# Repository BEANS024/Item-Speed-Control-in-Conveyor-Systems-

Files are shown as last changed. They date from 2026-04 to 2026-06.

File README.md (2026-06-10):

# **ITEM SPEED CONTROL IN CONVEYOR SYSTEMS FOR CONSISTENT ITEM DISCHARGE UTILIZING IR PROXIMITY SENSORS**

*A requirement to pass the course CONTROLS ENGINEERING & SENSORS ENGINEERING (collaborative requirement) - [A Semestral Project]*


<!-- isometric view of project -->





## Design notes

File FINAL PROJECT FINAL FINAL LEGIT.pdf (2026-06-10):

Republic of the Philippines

### BATANGAS STATE UNIVERSITY

The National Engineering University Alangilan Campus
Golden Country Homes, Alangilan Batangas City, Batangas, Philippines 4200
Tel Nos.: (+63 43) 425-0139 local 2121 / 2221
E-mail Address: coe.alangilan@g.batstate-u.edu.ph | Website Address: http://www.batstate-u.edu.ph (http://www.batstateu-u.edu.ph)
College of Engineering - Department of Electronics Engineering Bachelor of Science in Mechatronics Engineering

“Item Speed Control in Conveyor Systems for consistent inventory discharge utilizing IR Proximity Sensors”

ICE - 405 SENSORS ENGINEERING & ECE - 425 CONTROL SYSTEMS ENGINEERING

MExE-3202

Prepared by:

23-04314
23-00685
23-05791
23-04074

Instructor
Engr. JOHN KRISTOFFER L. JAVAREZ Engr. JONATHAN I. TEJADA

May 26, 2026
Leading Innovations, Transforming Lives, Building the Nation page 1

Alangilan Campus
Golden Country Homes, Alangilan Batangas City, Batangas, Philippines 4200
Tel Nos.: (+63 43) 425-0139 local 2121 / 2221
E-mail Address: coe.alangilan@g.batstate-u.edu.ph | Website Address: http://www.batstate-u.edu.ph (http://www.batstateu-u.edu.ph)
College of Engineering - Department of Electronics Engineering Bachelor of Science in Mechatronics Engineering

### I. Abstract

This project presents the design, mathematical modeling, simulation, and prototype implementation of a closed-loop conveyor object spacing control system utilizing infrared proximity sensors for consistent inventory discharge. The system employs an asymmetric Proportional-Integral (PI) control strategy implemented on an Arduino Uno microcontroller, using two HW201 infrared proximity sensors, an L298N motor driver module, and a custom 3D-printed conveyor belt driven by a TT DC gear motor. The control objective is to maintain a consistent inter-item discharge interval of 900 milliseconds by dynamically adjusting conveyor belt speed in response to real-time spacing feedback detected at the entry and discharge points of the conveyor.

The mathematical foundation was developed through transfer function and state-space modeling of the electrical, mechanical, electromechanical, and gear subsystems. An asymmetric PI control law with separate braking and accelerating gain sets was implemented alongside anti-windup protection, asymmetric PWM ramping, and a feed-forward pre-compensation mechanism to mitigate the belt's inherent transport delay. A First-In First-Out queue structure preserves measurement-to-item correspondence during multi-object operation.

MATLAB and Simulink were used for system analysis and simulation, supported by an interactive digital twin for controller validation prior to hardware deployment. Prototype testing under close-spacing, far-spacing, and mixed-spacing conditions confirmed the system's ability to apply accurate bidirectional corrective actions. Results demonstrate the effectiveness of closed-loop PI control in improving conveyor discharge consistency, accuracy, and adaptability for industrial automation applications.

Leading Innovations, Transforming Lives, Building the Nation page 2

Alangilan Campus
Golden Country Homes, Alangilan Batangas City, Batangas, Philippines 4200
Tel Nos.: (+63 43) 425-0139 local 2121 / 2221
E-mail Address: coe.alangilan@g.batstate-u.edu.ph | Website Address: http://www.batstate-u.edu.ph (http://www.batstateu-u.edu.ph)
College of Engineering - Department of Electronics Engineering Bachelor of Science in Mechatronics Engineering

### II. Introduction

This project titled “Item Speed Control in Conveyor Systems for consistent inventory discharge utilizing IR Proximity Sensors” seeks to portray in small scale how closed-loop PI controllers can be utilized in conveyor systems. The project uses a custom designed 3D printed conveyor system which utilizes a DC gear motor to drive and actuate the conveyor belt. The entire logic of the system is programmed and controlled through an arduino uno along with two infrared proximity sensors that are used to detect the presence and determine the spacing of objects along the conveyor belt. By utilizing the detection signals produced by the infrared sensors, object spacing can be monitored and belt discharge can be controlled. If the said objects are too close to one another the system would slow down to prevent item congestion in a supposed station after the belt, and if objects were to have a further distance from one another than the target set point the system would speed up for the second object to compensate for delivery delay.

Engineering an automated system that integrates mechanics, electronics, and computing into a singular system is the interdisciplinary engineering field of mechatronics, however being able to control every component to work in unison to function as a singular system is only the next step into mechatronics engineering. Closed-loop control is an essential concept in mechatronics for automated systems because it allows continuous operations based on real-time feedback within the system. Unlike open-loop systems, which operate without considering the actual output condition, closed-loop systems utilize sensors to detect system behavior and provide feedback to the controller for corrective action. This enables the system to maintain accuracy, stability, and consistent performance even when disturbances or varying operating conditions are present. It is widely used in industrial automation, robotics, conveyor systems, motor speed regulation, and manufacturing processes where maintaining controlled and stable Leading Innovations, Transforming Lives, Building the Nation page 3

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

operation is critical. Through continuous feedback and adjustment, closed-loop control helps minimize errors, reduce manual intervention, improve safety, and optimize overall system performance. In the proposed conveyor speed control system, applying a closed-loop control plays an essential role in this system for monitoring and regulating inventory speed along the conveyor belt for maintaining a consistent inventory discharge rate. By applying closed-loop control in this project, the project design achieves being an automated mechatronic system which improves efficiency, precision, and reliability by allowing machines to adapt automatically to change within the system. Unlike traditional conveyor systems with no such application of logic controllers, this system obtains its feedback for its closed loop system from the infra-red proximity sensors allowing the controller to dynamically adjust the conveyor speed in response to changing conditions. This adaptive behavior demonstrates the practical importance of closed-loop control in achieving efficient and reliable automated material handling operations

OBJECTIVES:

1. To design a proportional control system for conveyor belts that maintains optimal

material flow by adjusting speed based on inventory item flow, and its

corresponding mathematical control model.

2. To develop a belt control system that implements the functionality of an IR sensor

module to regulate item flow for consistent discharge.

3. To analyze and evaluate the system’s performance in terms of the following
- Speed response
- Control accuracy
- Sensor reliability

Leading Innovations, Transforming Lives, Building the Nation page 4

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

### III. System Description

HARDWARE CONFIGURATION
The system is tailored to showcase the application of a closed-loop feedback architecture in automated conveyor systems. The overall mechanical hardware design is structured so the project is suited for safe DC power. The primary power supply supplies approximately 13.7V that is then regulated through a LM2596 DC-DC step-down buck converter. To improve the electrical safety of the electrical components in this project, a toggle switch is used as the main power switch, so current doesn't flow immediately after plugging in the power supply. Two limit switch push buttons are then utilized to create a start and stop function in the project, this allows for confirmation that all components are functional before manually starting the system and when observation is done the system can them be manually and safely switched off without aggressively unplugging the power, this also allows the operator to manually switch off the project if any errors were to occur and then resetting via the start button. Further hardware configuration can be observed in figure 2.1.

Leading Innovations, Transforming Lives, Building the Nation page 5

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

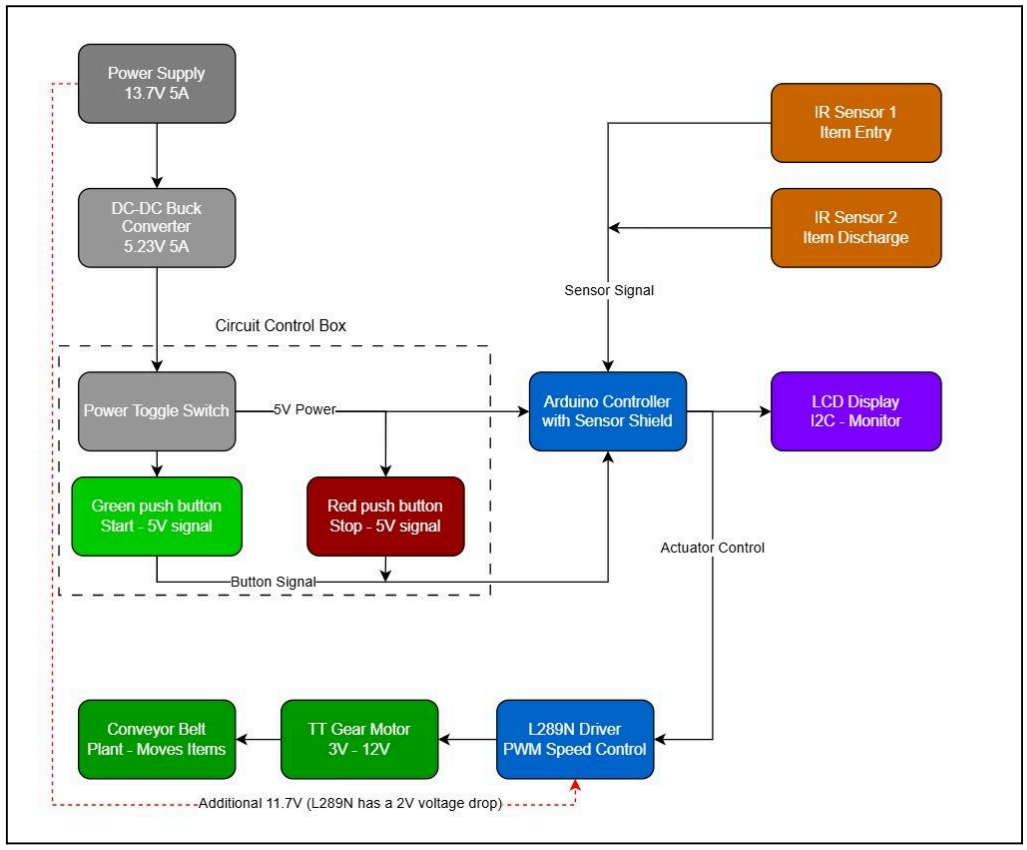
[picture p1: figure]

“figure 2.1. (Hardware Configuration)” SENSOR

The sensor to be used in this system is a HW201 Infrared (IR) Sensor. This sensor measures and detects the infrared radiation which is emitted from the TR transmitter and when it hits an object the radiation would then be reflected into the IR receiver. This process is then utilized to create a signal output. When no radiation is reflected, the electrical resistance is increased, then if radiation is reflected, the resistance will decrease (resistance will vary on the distance it was reflected from).

Leading Innovations, Transforming Lives, Building the Nation page 6

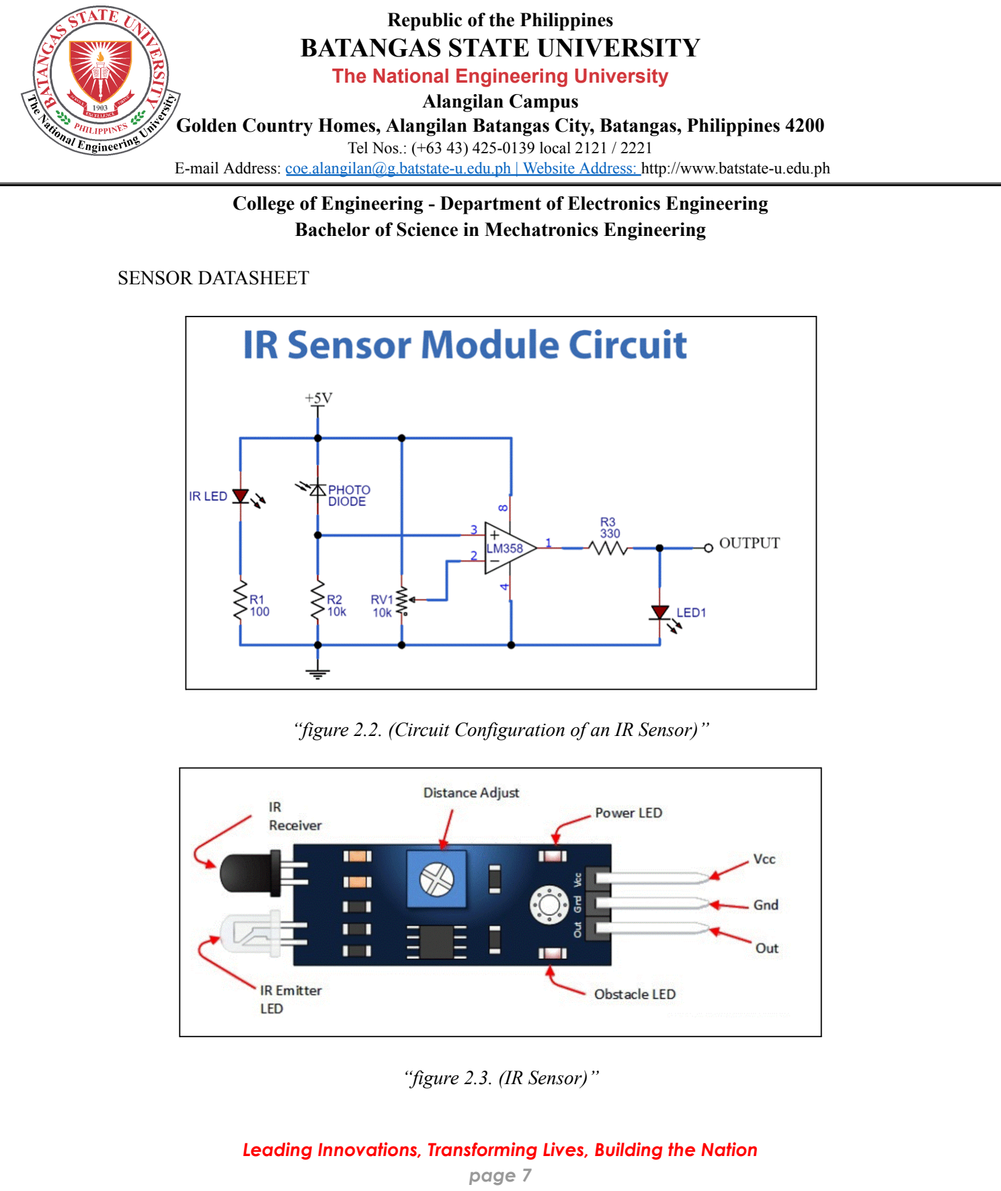
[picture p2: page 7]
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

SENSOR DATASHEET

“figure 2.2. (Circuit Configuration of an IR Sensor)”

“figure 2.3. (IR Sensor)”

Leading Innovations, Transforming Lives, Building the Nation page 7

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

Pinouts of HW201 Module

PIN NAME | DESCRIPTION
VCC | Power Supply Input
GND | Power Supply Ground
OUT/SIGNAL | Active High Output

SPECIFICATIONS

- Main Chip: LM393
- Detection Distance: 2~30cm
- Detection Angle: 35 °
- Working Voltage: 3.3V~5V
- Board Size: 31 * 14mm / 1.22 * 0.55in
- Board Weight(1pc): 3g
- 20mA supply current
- 2 to 30cm adjustable sensing range (on-board Potentiometer)

SENSOR CONDITIONING

The HW201 infrared (IR) sensor module utilizes an LM358 operational amplifier to perform signal conditioning on the output of the IR receiver. When infrared light emitted by the transmitter is reflected by a nearby object and detected by the photodiode (or phototransistor), it generates a small analog voltage proportional to the reflected intensity. However, this signal is typically weak and susceptible to noise, making it unsuitable for direct use in control systems.

Leading Innovations, Transforming Lives, Building the Nation page 8

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

To address this, the LM358 op-amp is configured as a comparator with adjustable threshold. One input of the LM358 receives the analog signal from the IR receiver, while the other input is connected to a reference voltage set by an onboard potentiometer. The amplifier compares these two voltages and produces a clean digital output: when the sensor signal exceeds the threshold, the output switches state (HIGH or LOW), indicating object detection.

This signal conditioning process improves reliability by amplifying the weak sensor signal, filtering out minor fluctuations, and converting it into a stable, noise-resistant digital signal that can be easily interfaced with microcontrollers such as an Arduino or PLC systems.

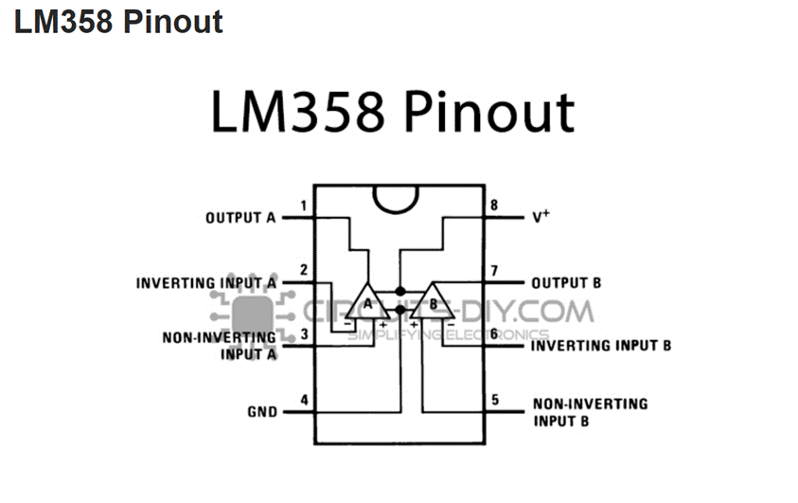
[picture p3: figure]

“figure 2.4. (IR Sensor Op-Amp)”

Leading Innovations, Transforming Lives, Building the Nation page 9

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

IMPLEMENTATION OF THE SENSOR IN THE SYSTEM

To manage the flow of inventory items within the system, an IR proximity sensor is implemented to detect discrete events corresponding to item entry onto the conveyor belt. Each detection provides a measurable signal indicating the presence of an item, enabling the system to track the timing and frequency of incoming materials. This event-based sensing approach allows the system to estimate the infeed rate and monitor consistency in item flow. The acquired data is then used as feedback for adjusting conveyor speed to maintain a stable discharge rate. By integrating discrete sensing with control logic via an Arduino Uno, the system achieves more reliable and responsive inventory handling.

ELECTRICAL DESIGN
An arduino uno R3 is used as this project's main embedded microcontroller to handle the project’s logic and control calculations. The I2C ports are used so the operator can monitor the real time speed, gap, item count, and error in the system. The DC-DC buck converter ensures that approximately 5.23V is used to power the electrical components and the 13.7V from the power supply is used as additional power for the TT gear motor wish has an operating voltage of 3-12V, in this set up 13.7V is used because as the additional voltage flows through the motor driver module L298N there is a 2V voltage drop. Then two infra-red proximity sensors are connected to the arduino board, because the system only requires the sensors to be used to detect objects entering and leaving the belt, the sensors deliver discrete signals to the digital GPIO’s.

Leading Innovations, Transforming Lives, Building the Nation page 10

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

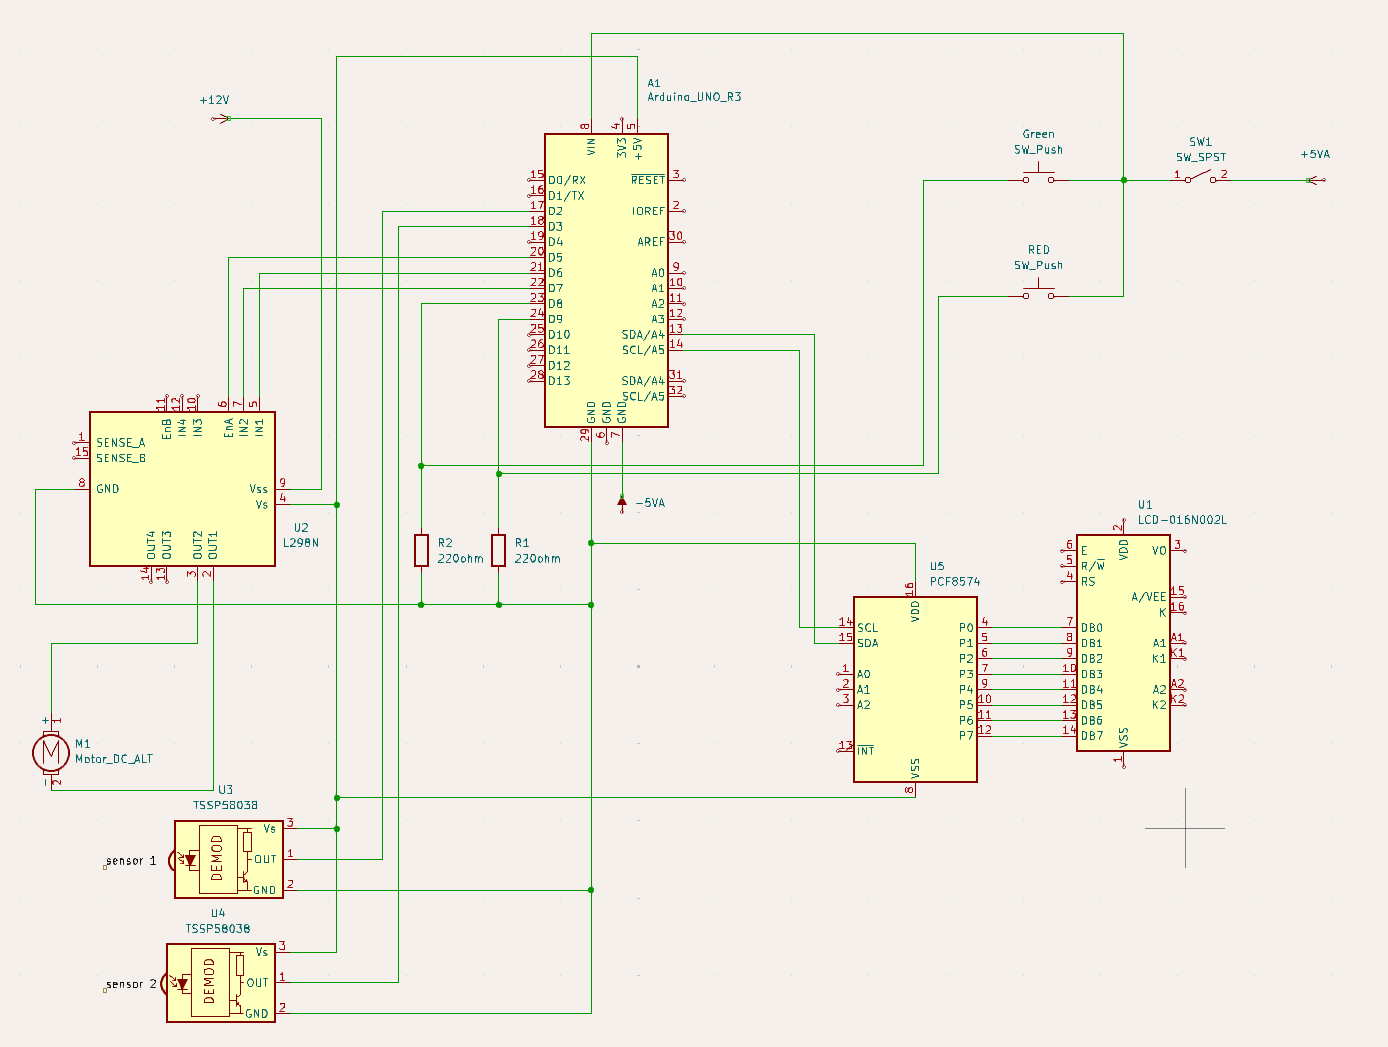
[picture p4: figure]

“figure 2.5. (Electrical Schematic)”

CAD DESIGN AND MANUFACTURING
The project was then designed on Solidworks to have a conceptual design before physically assembling it. The system features a custom made conveyor belt which utilizes a custom made timing belt design. The belt length is 368mm from the gear to gear centers. The custom parts were then 3D printed with PETG, the total mass used for the prints is 527.73g. The parts manufactured for this project consists of an inflow ramp which has a 30 degree angle of tilt and a mounting slot for the infra-red proximity sensor. A vertical elevation support for the LCD display which allows the operator to view the real-time system conditions at a comfortable viewing angle. For the system discharge a basket is placed to receive items that will be discharged from the conveyor system. screw supports were made for the conveyor belt to hold it Leading Innovations, Transforming Lives, Building the Nation page 11

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

in place while retaining the modular ability of the conveyor if modifications are needed. As for the conveyor itself, a motor chassis was made to hold the DC motor in place and to protect it from external disturbances. Two gears are present in the conveyor system, one being the driver pulley and the other being the driven pulley. The frame of the conveyor system is designed to hold the belt in a fixed position to prevent belt slack without the need of additional tension. Finally for the belt, it uses a timing belt structure to allow it to be driven by the pulleys by having both rigid bodies interlock with each other. To achieve the timing belt design 98 individual pieces were printed using a print in place technique with a 0.5mm tolerance to allow for optimal flexibility of the belt for the conveyor system.

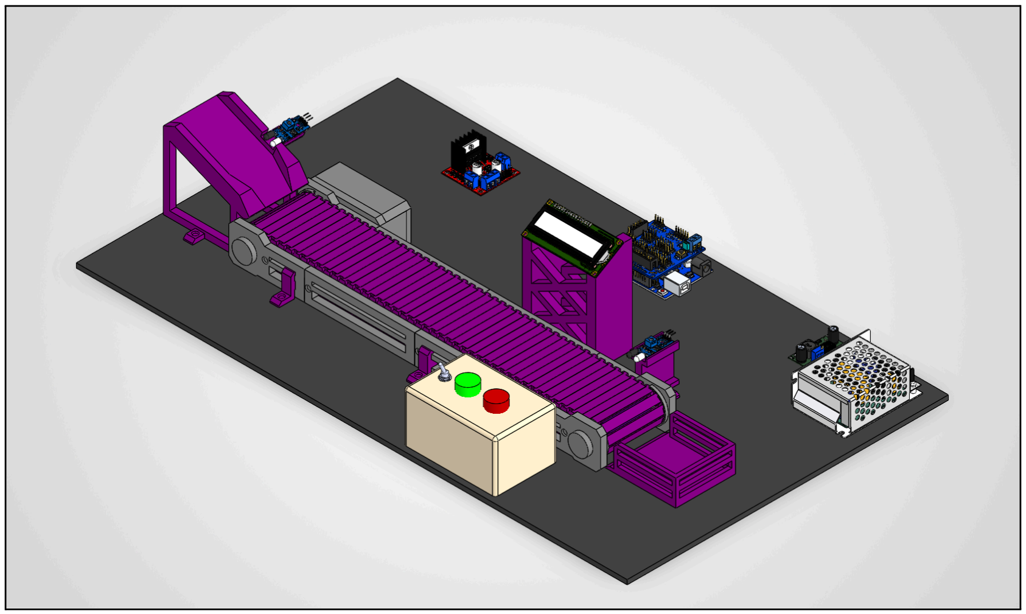
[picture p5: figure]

“figure 2.6. (CAD Isometric view)”

Leading Innovations, Transforming Lives, Building the Nation page 12

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

“figure 2.7. (CAD Top view)

“figure 2.8. (CAD Front view)”

Leading Innovations, Transforming Lives, Building the Nation page 13

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

CONTROL SYSTEM

For this automated conveyor system where speed control is the main variable to be controlled, figure 2.9. provides a basic input output diagram of how the system works overall. where items entering the conveyor serves as the input then the conveyor system regulates the speed ensuring that the items on the belt are discharged consistently. The items that are discharged from the conveyor belt would also be the output of the system.

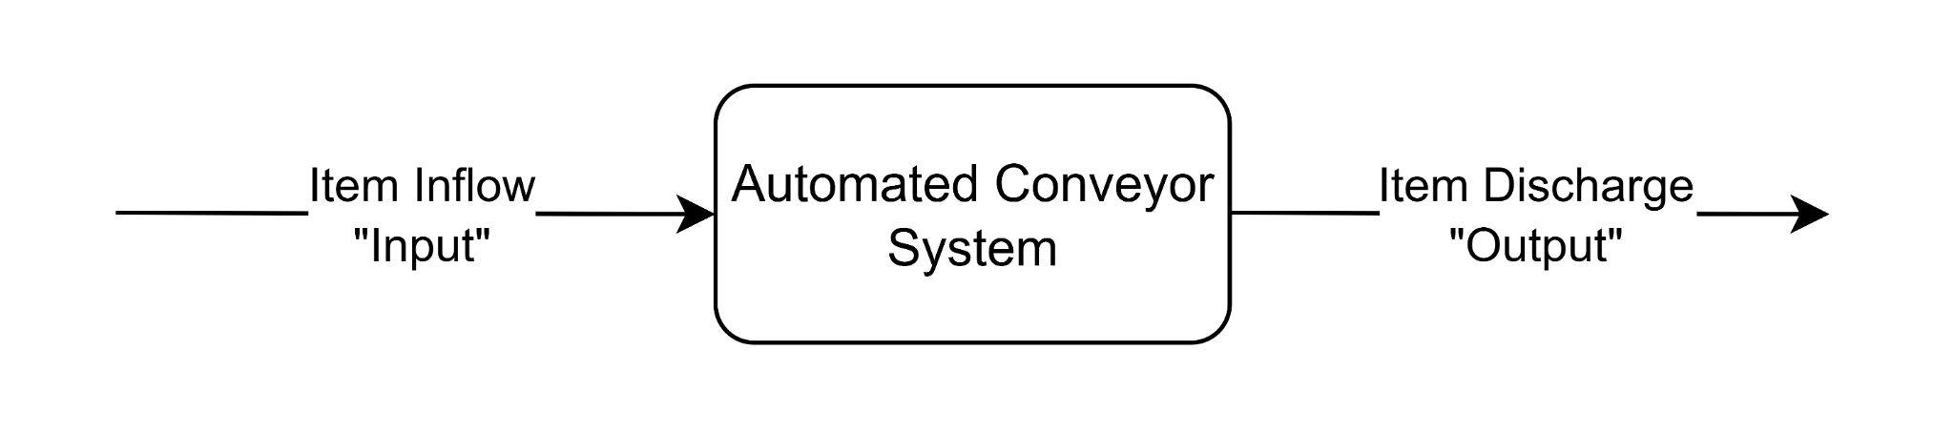
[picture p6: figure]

“figure 2.9. (Basic input output diagram)”

In this automated conveyor system, maintaining a consistent discharge rate is essential for material handling in automated systems especially in industrial applications. For the control law to be applied to this project its important to choose the most appropriate PID controller was considered, however it was deemed overly complex for this system since the main priority is creating a stable system response and reducing steady state errors, there is no need for the system to predict errors also this effects the arduino computational load hindering the response time of the system.

Leading Innovations, Transforming Lives, Building the Nation page 14

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

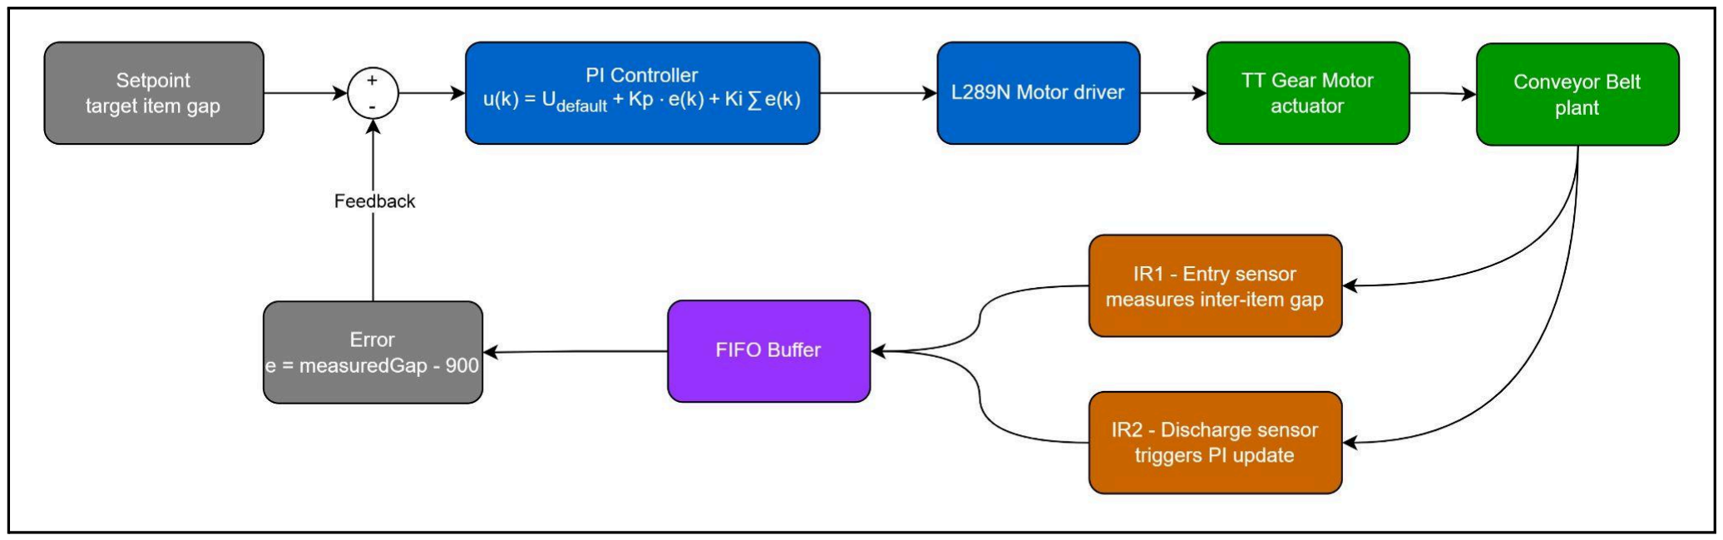
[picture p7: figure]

“figure 2.10. (Block diagram of the closed-loop system)”

### Controller Type

PI Control law(Asymmetric Gains)

With gain selection based on error sign:

Condition | Meaning
e(k)<0 | Items too close → slow down | 0.18 | 0.005
e(k)≥0 | Items too far → speed up | 0.07 | 0.002

Udefault = 110 (PWM), with output clamped: 90≤u(k)≤200

Leading Innovations, Transforming Lives, Building the Nation page 15

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

Anti-Windup (Conditional Integration)

The integral only accumulates when the output is not saturated in the direction of the error:

integrate if:

Integral is also hard-clamped: −1000≤∑e≤1000, limiting the maximum integral contribution to ±5PWM units.

Asymmetric PWM Ramp (Motor Actuator)

Deceleration is 2.5× faster than acceleration — prevents item pile-up on sudden slowdown.

Feed-Forward Trigger Condition

This is a pre-emptive, one-shot speed reduction that fires midway through the belt's ~2 s transport delay. IR2's PI output always cancels and overrides it upon item exit.

Inter-Item Gap Measurement (at IR1)

Leading Innovations, Transforming Lives, Building the Nation page 16

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

Measured only for intra-batch items (when before the new arrival) to prevent phantom cross-batch gaps from entering the FIFO queue.

Error Signal

Where TARGET_GAP = 900 ms. This is computed event-driven — once per item exit at IR2, not every loop tick.

The overall architecture is a feedback PI controller with a feed-forward pre-compensation path. The PI loop closes at IR2 (exit), while the feed-forward path acts at IR1 (entry) to reduce the impact of the ~2-second transport delay, a classic Smith Predictor-inspired approach adapted for discrete, event-driven control.

Leading Innovations, Transforming Lives, Building the Nation page 17

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

### IV. Mathematical Modeling

### 4.1 Transfer Function Modeling

ELECTRICAL SYSTEM
The mathematical model for this project's electrical system is derived from its own electrical circuit. To convert the enter circuit into a RLC circuit for the mathematical modelling, all modules used in this circuit are assumed to be load resistors, the resistance of each component was measured from their respective VCCs to GNDs. For the arduino board, the resistance is measured from its VCC to its Vout where the voltage would flow to supply the respective circuit components. The motor driver module exhibits two voltage ins and a shared ground, two load resistors are then assumed from this module, one that connects the additional voltage directly from the power supply and one that attains voltage directly from the arduino board.

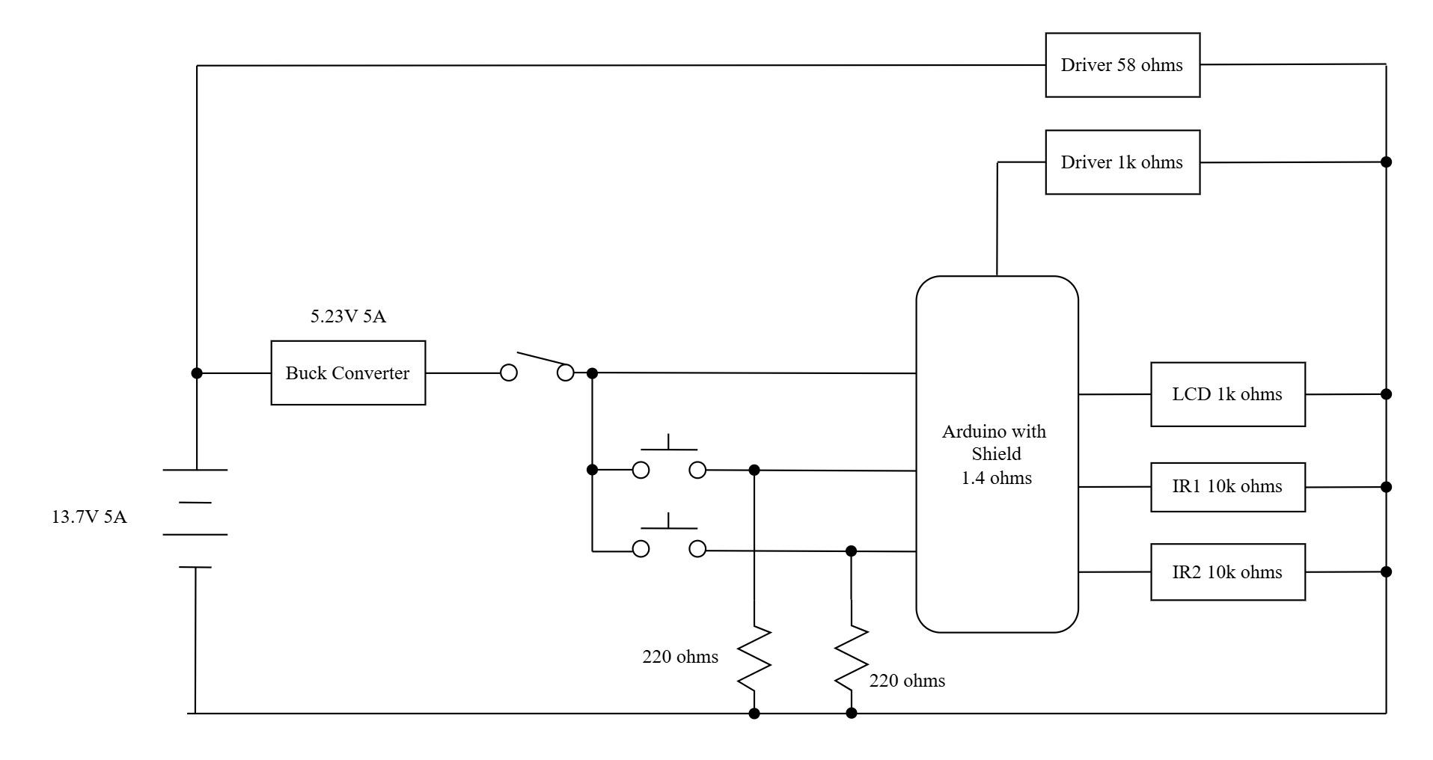
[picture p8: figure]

“figure 4.1. Electrical System” Leading Innovations, Transforming Lives, Building the Nation page 18

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

Loop 1

Loop 2

Loop 3

Loop 4

Leading Innovations, Transforming Lives, Building the Nation page 19

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

Loop 5

Loop 6

Leading Innovations, Transforming Lives, Building the Nation page 20

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

Leading Innovations, Transforming Lives, Building the Nation page 21

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

Final Transfer Function

TRANSLATIONAL MECHANICAL SYSTEM

something something technical statements

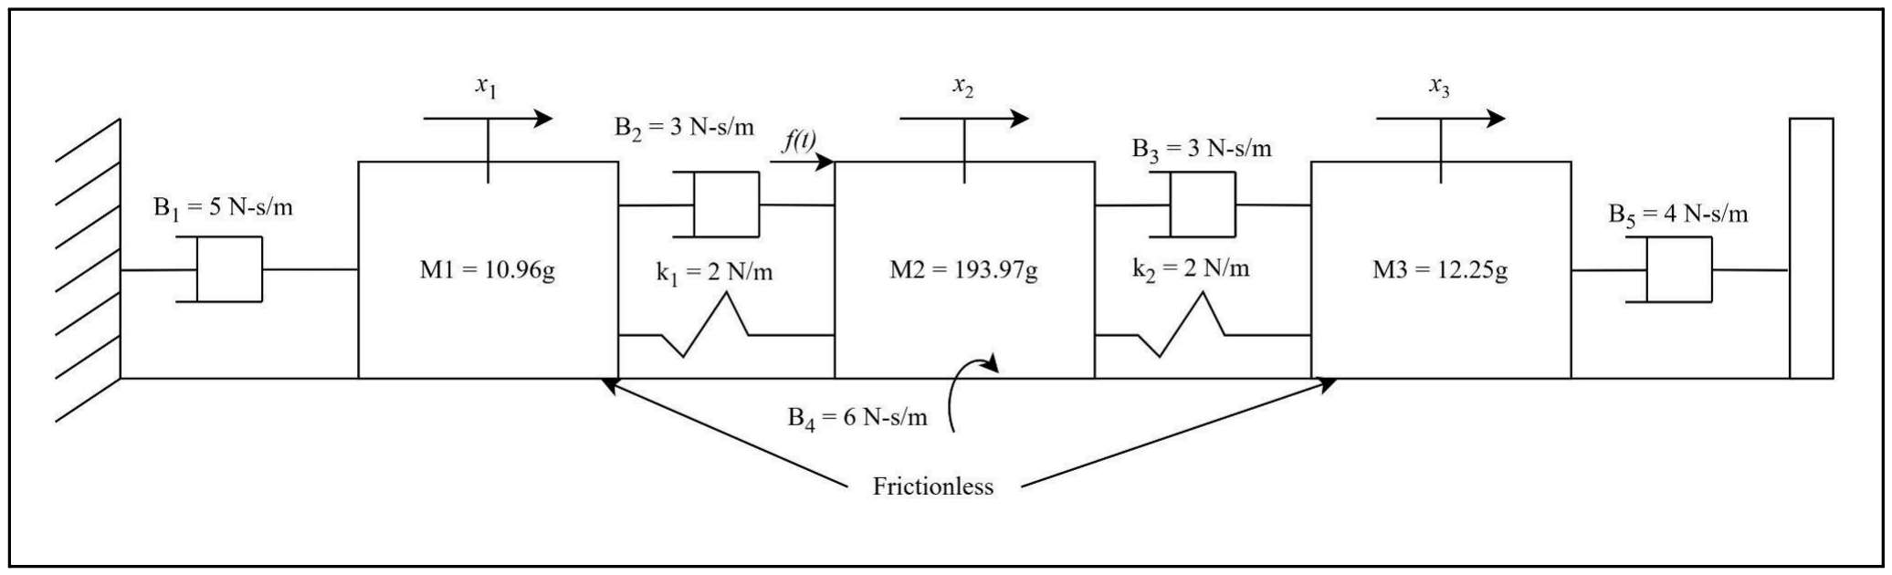
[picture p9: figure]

“figure 4.2. Translational System”

Leading Innovations, Transforming Lives, Building the Nation page 22

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

Leading Innovations, Transforming Lives, Building the Nation page 23

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

Leading Innovations, Transforming Lives, Building the Nation page 24

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

Leading Innovations, Transforming Lives, Building the Nation page 25

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

Final Transfer Function

ROTATIONAL MECHANICAL SYSTEM

The rotational system of the project mainly focuses on the main motor shaft along with the driver pulley and driven pulley of the conveyor belt. J1 represents the motor shaft that is connected in series with the driver pulley, their connection experiences friction along the conveyor frame and the connection between two rigid bodies also experiences torsional stiffness. A spring and damper are used to connect J2 with J3 which also represents the belt. The dampers b2, b3, and b4 represent the friction the pulleys experience in connection with the conveyor frame.

Leading Innovations, Transforming Lives, Building the Nation page 26

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

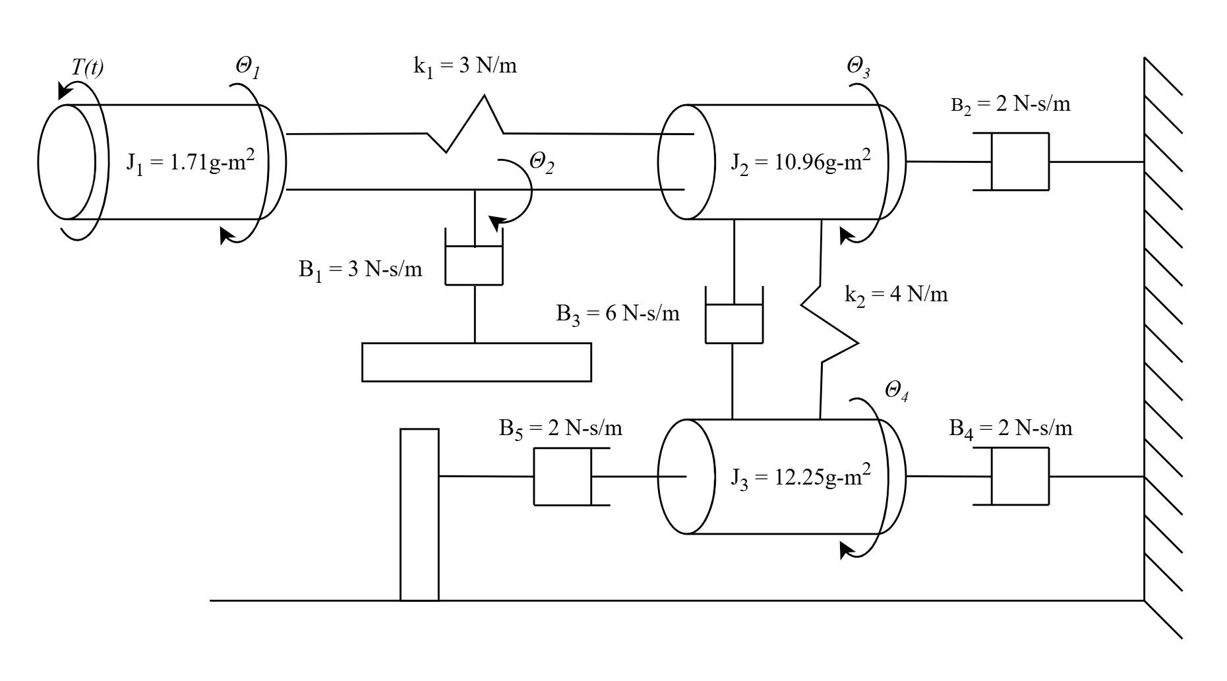
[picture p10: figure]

“figure 4.3. Rotational System”

Leading Innovations, Transforming Lives, Building the Nation page 27

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

Leading Innovations, Transforming Lives, Building the Nation page 28

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

Leading Innovations, Transforming Lives, Building the Nation page 29

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

Leading Innovations, Transforming Lives, Building the Nation page 30

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

Leading Innovations, Transforming Lives, Building the Nation page 31

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

Final Transfer Function

ELECTROMECHANICAL SYSTEM

Leading Innovations, Transforming Lives, Building the Nation page 32

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

“figure 4.4. Electromechanical System”

Leading Innovations, Transforming Lives, Building the Nation page 33

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

Leading Innovations, Transforming Lives, Building the Nation page 34

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

Final Transfer Function:

GEAR SYSTEM

Leading Innovations, Transforming Lives, Building the Nation page 35

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

The gear system model of this project mainly represents how the pulleys and the timing belt gear with each other. The driver pulley J1 has gear movement with the timing belt. Then the timing belt also presents a gear movement with the driven pulley J2.

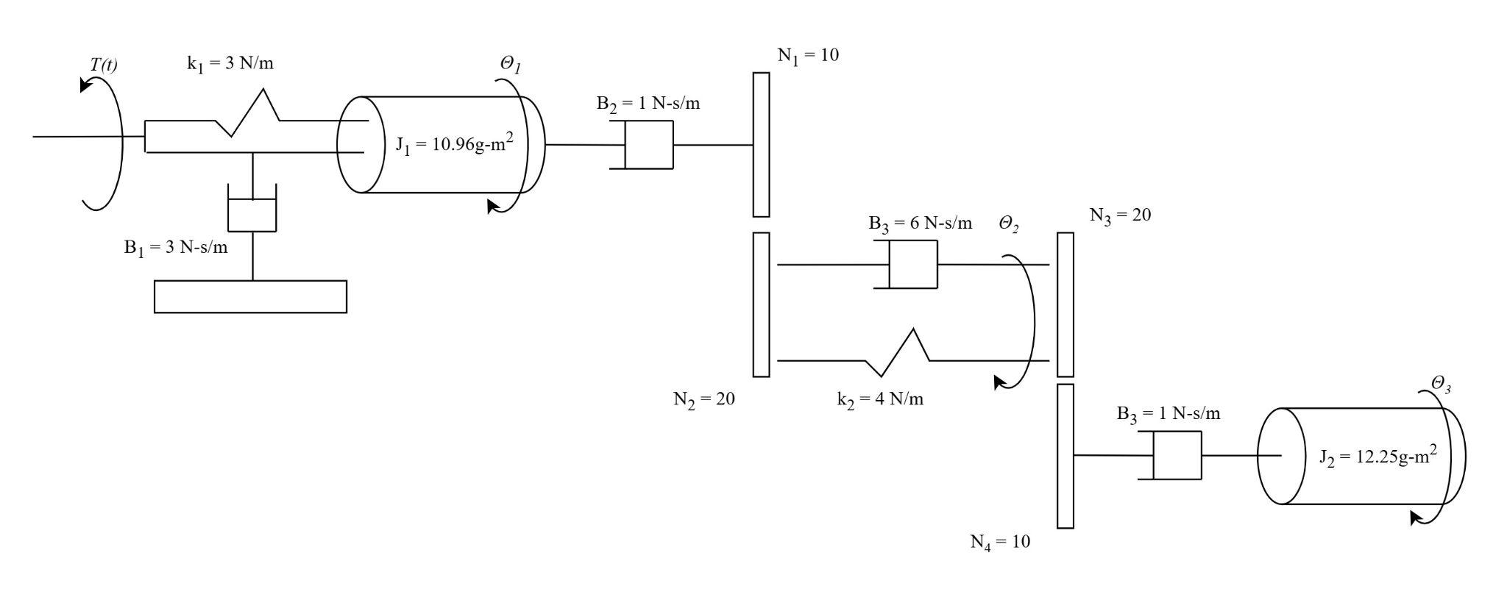
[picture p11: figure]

“figure 4.5. Gear System”

\

Leading Innovations, Transforming Lives, Building the Nation page 36

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

Leading Innovations, Transforming Lives, Building the Nation page 37

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

Leading Innovations, Transforming Lives, Building the Nation page 38

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

Final Transfer Function

4.2 State-Space Representation

State-Space Representation for the Translational Dynamic System

Leading Innovations, Transforming Lives, Building the Nation page 39

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

State Space Matrices

Leading Innovations, Transforming Lives, Building the Nation page 40

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

Leading Innovations, Transforming Lives, Building the Nation page 41

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

Leading Innovations, Transforming Lives, Building the Nation page 42

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

State-Space Representation for Rotational Dynamic System

State Space Matrices

Leading Innovations, Transforming Lives, Building the Nation page 43

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

Leading Innovations, Transforming Lives, Building the Nation page 44

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

Leading Innovations, Transforming Lives, Building the Nation page 45

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

State-Space Representation for the Electromechanical Dynamic System

State Space Matrices

Leading Innovations, Transforming Lives, Building the Nation page 46

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

State-Space Representation for the Gear Dynamic System

Leading Innovations, Transforming Lives, Building the Nation page 47

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

State Space Matrices

Leading Innovations, Transforming Lives, Building the Nation page 48

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

### V. Time Response Analysis

The zoomed-out step response graph illustrates the overall behavior of the conveyor belt

PI control system over a longer period of operation. The response shows how the controller continuously adjusts the conveyor speed in reaction to spacing errors detected by the IR proximity sensors. Oscillatory behavior can be observed due to repeated corrections made by the PI controller as the system attempts to maintain the desired item spacing set point. The increasing oscillation magnitude demonstrates the sensitivity of the system to sustained disturbances and varying item intervals along the conveyor belt.

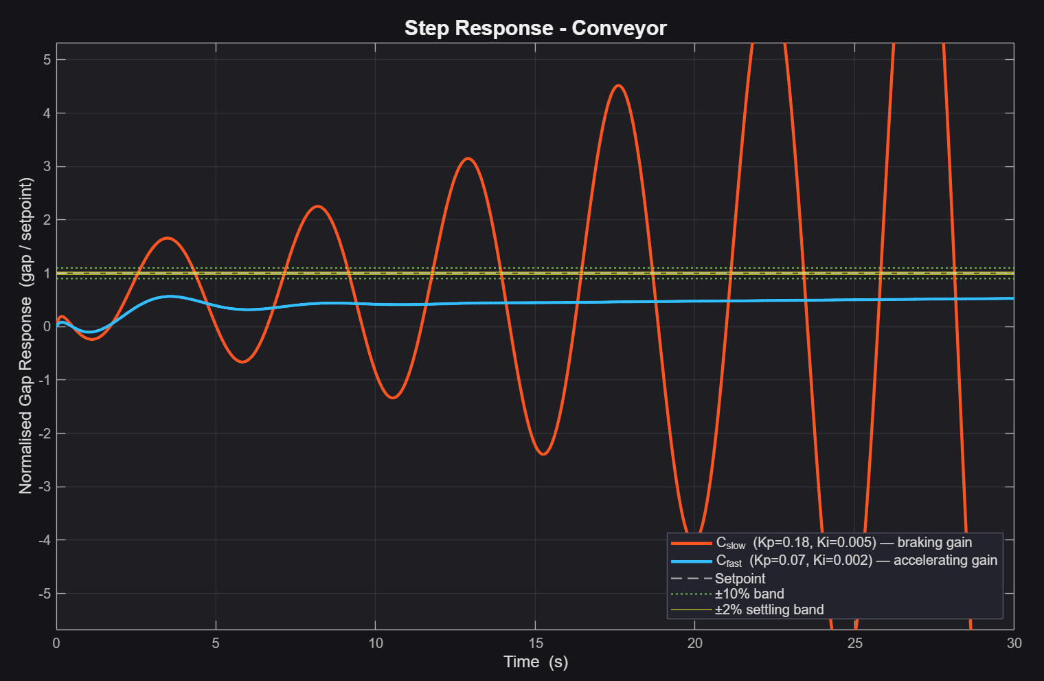
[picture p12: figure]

“figure 5.1. Step Response zoomed out"

Leading Innovations, Transforming Lives, Building the Nation page 49

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

The zoomed-in step response provides a closer observation of the transient response characteristics of the system immediately after a spacing disturbance occurs. The graph shows the rise time, overshoot, and settling behavior of the PI controller as it attempts to stabilize the conveyor discharge interval. Initially, the system reacts aggressively to spacing errors, causing temporary oscillations before gradually approaching the desired operating condition. This demonstrates the controller’s capability to dynamically regulate belt speed in response to changing object spacing conditions.

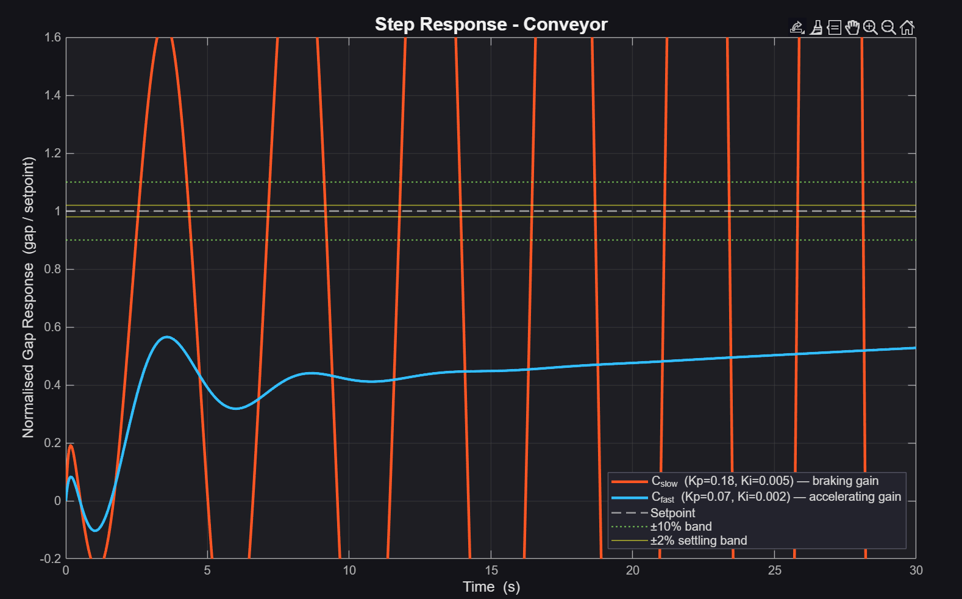
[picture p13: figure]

“figure 5.2. Step Response zoomed in”

Leading Innovations, Transforming Lives, Building the Nation page 50

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

This figure compares the system response under two operating conditions: items positioned too close together and items positioned farther apart than the target spacing. When objects are too close, the controller reduces conveyor speed to prevent congestion at the discharge area. Conversely, when objects are too far apart, the controller increases belt speed to compensate for delayed delivery. The graph demonstrates the adaptability of the PI controller in maintaining consistent inventory discharge despite varying item intervals.

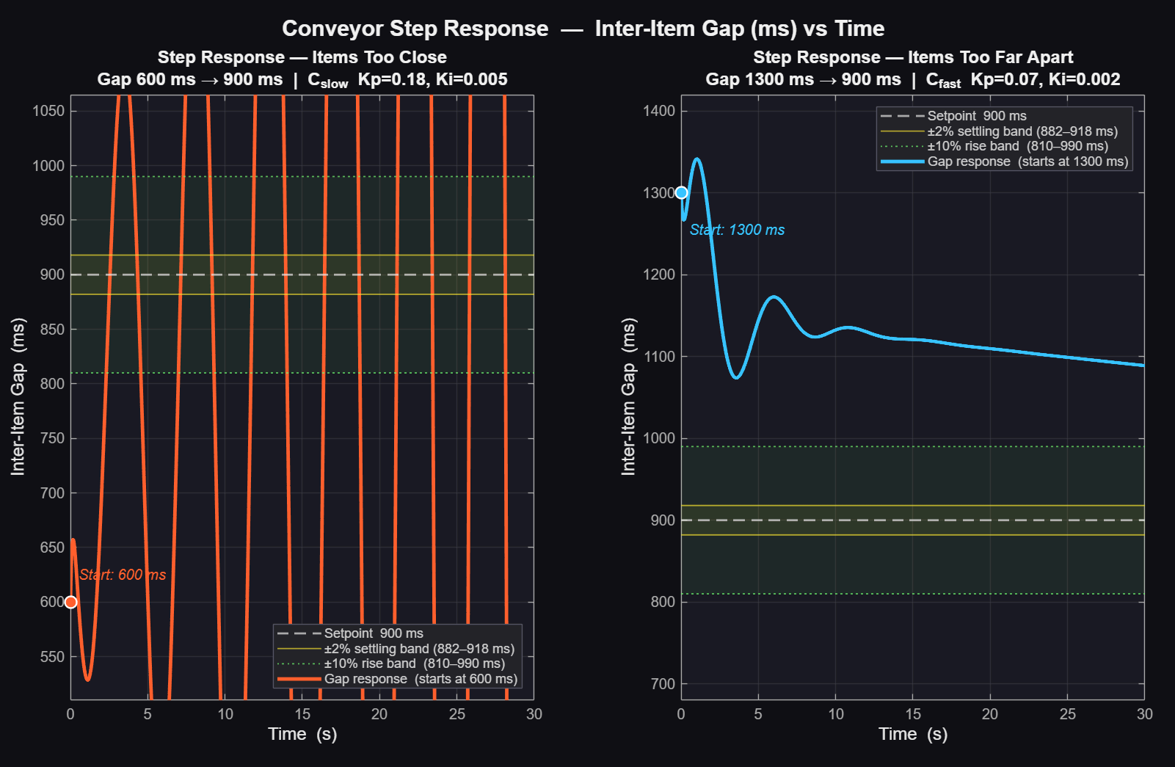
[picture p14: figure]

“figure 5.3. Step Response (close & far apart item scenarios)”

Leading Innovations, Transforming Lives, Building the Nation page 51

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

The impulse response graph represents the reaction of the conveyor system to a sudden spacing disturbance or abrupt detection event. The response exhibits oscillatory characteristics caused by the controller attempting to quickly correct the error introduced into the system. Over time, the controller works to reduce the effect of the disturbance and stabilize the conveyor operation. This behavior highlights the responsiveness of the closed-loop PI control system in handling sudden changes in item spacing conditions.

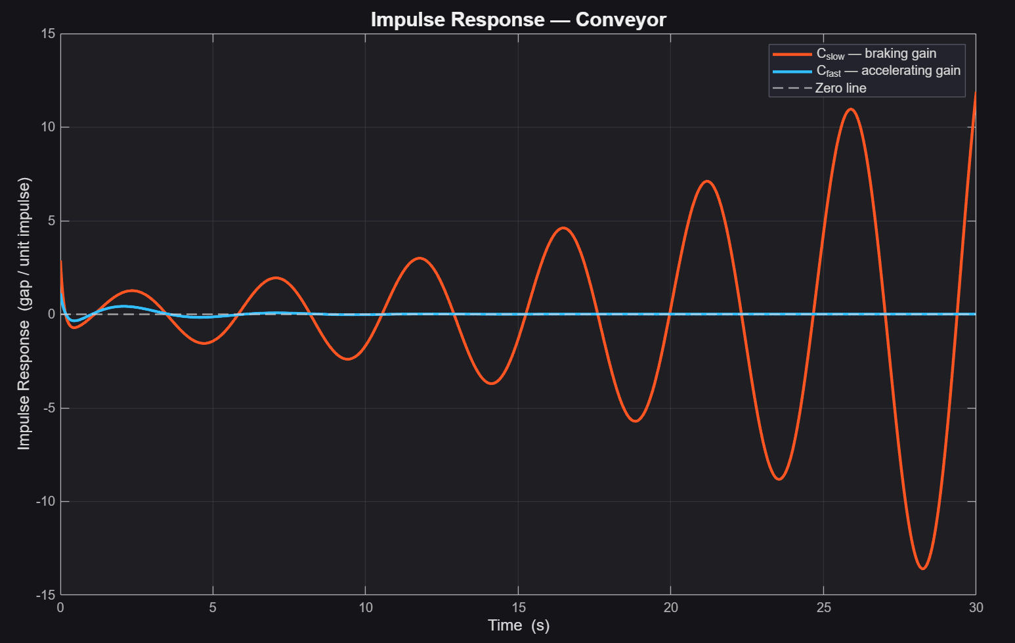
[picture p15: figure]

“figure 5.4. Impulse Response”

Leading Innovations, Transforming Lives, Building the Nation page 52

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

This graph illustrates the impulse response of the conveyor system for both close-spacing and far-spacing disturbances. The system produces different corrective actions depending on the detected spacing condition. Larger corrective responses are observed when items are significantly closer or farther from the desired set point, indicating stronger controller action to restore proper spacing. The graph confirms that the controller can react dynamically to sudden disturbances while maintaining operational stability.

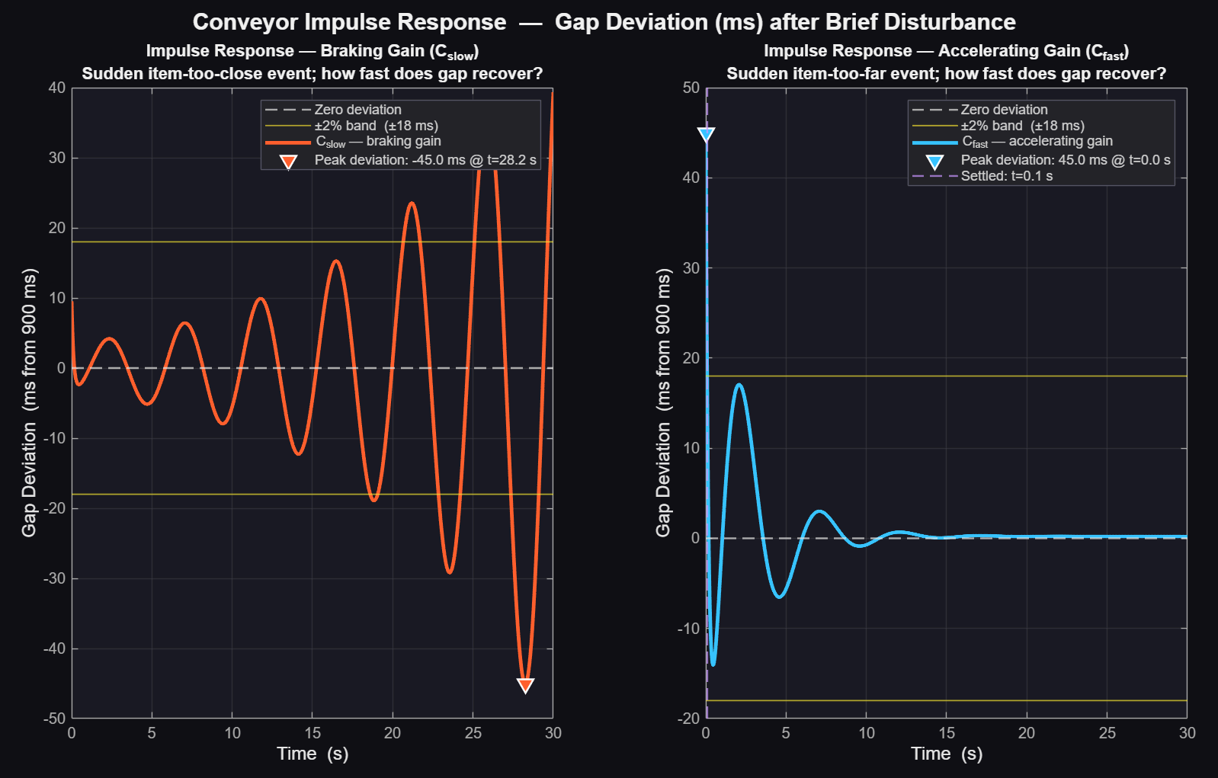
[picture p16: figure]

“figure 5.5. Impulse Response (close & far item scenarios)”

Leading Innovations, Transforming Lives, Building the Nation page 53

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

The key performance metrics comparison summarizes important transient response characteristics of the conveyor control system, including rise time, settling time, overshoot, and steady-state error. The comparison highlights the differences in controller behavior between close-item and far-item operating conditions. Variations in these metrics indicate how the PI controller responds differently depending on the magnitude and direction of the spacing error. Overall, the graph demonstrates the effectiveness of the controller in minimizing steady-state error while maintaining acceptable response performance.

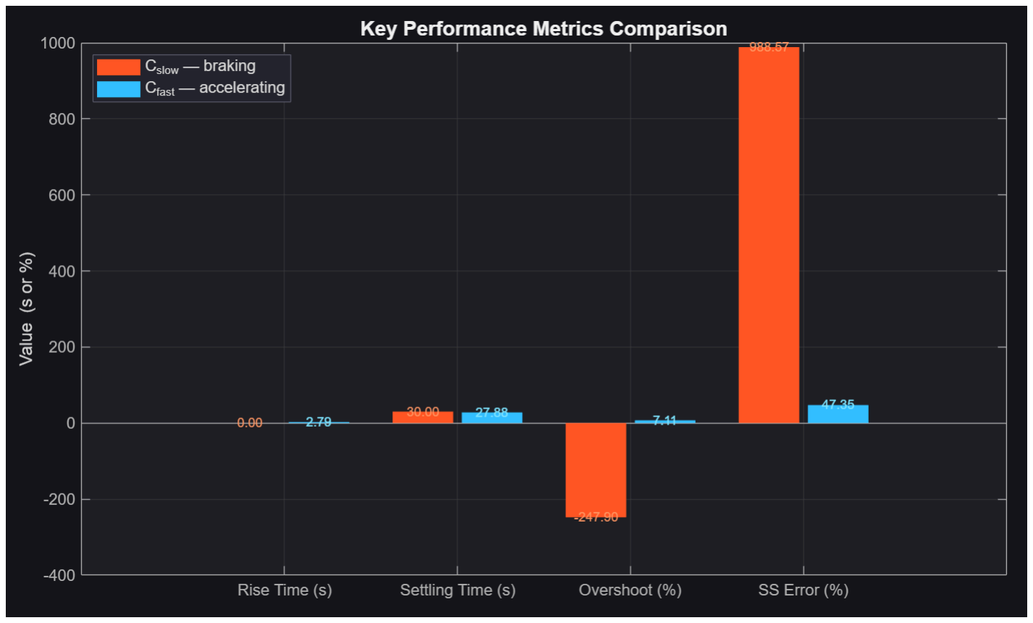
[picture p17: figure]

“figure 5.6. Key Performance Metrics Comparison”

Leading Innovations, Transforming Lives, Building the Nation page 54

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

The error signal graph shows the difference between the desired spacing set point and the actual measured spacing over time. Positive and negative error values indicate whether items are too close together or too far apart, respectively. The oscillating nature of the error signal reflects the continuous corrective action performed by the PI controller as it regulates conveyor speed. Although transient oscillations are present, the controller continuously works to minimize the error and maintain consistent item discharge spacing.

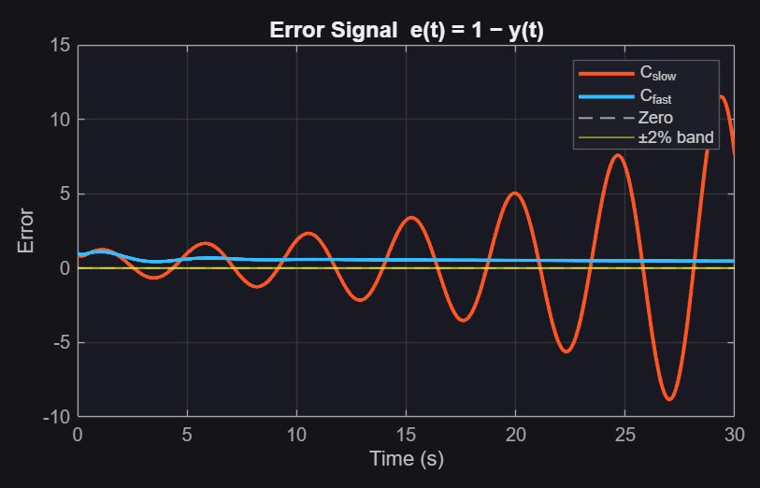
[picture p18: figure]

“figure 5.7. Error Signal”

Leading Innovations, Transforming Lives, Building the Nation page 55

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

### VI. MATLAB Implementation

Modeling using MATLAB/Simulink

The conveyor belt PI control system was modeled and simulated using MATLAB/Simulink to validate the mathematical model and evaluate controller performance prior to physical prototype implementation. The Simulink environment provided a platform for implementing the closed-loop control architecture derived from the system's electromechanical transfer function, allowing observation of system behavior under various spacing conditions without the constraints of physical hardware limitations.

The simulation model was built around the derived electromechanical transfer function:

This transfer function served as the plant model within the Simulink block diagram, representing the dynamic relationship between the applied armature voltage and the resulting motor shaft angular displacement. The transfer function captures the dominant dynamic behavior of the DC gear motor driving the conveyor belt, including the effects of combined inertia and damping derived from the gear system analysis.

Figure 6.1 presents the complete Simulink block diagram of the closed-loop conveyor PI control system. The simulation architecture consists of several interconnected subsystems that mirror the physical hardware configuration of the prototype. A reference setpoint of 900 ms representing the target inter-item gap is fed into a summing junction where the error signal is Leading Innovations, Transforming Lives, Building the Nation page 56

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

computed by subtracting the measured gap feedback. The error signal is then processed by a discrete-time PI controller block, labeled PI(z), which computes the corrective control output based on the asymmetric gain structure of the implemented controller. The PI controller output is subsequently passed through a saturation block that enforces the defined PWM operating limits of 90 to 200, preventing actuator saturation and protecting the motor from out-of-range commands. A unity gain summing block combines the PI output before it is applied to the electromechanical transfer function block representing the conveyor motor plant. The output of the plant block corresponds to the inter-item gap measured at the discharge sensor IR2. A transport delay element represented by the Z⁻¹⁰ block was incorporated into the feedback path to simulate the belt's inherent transport delay between the entry sensor IR1 and the discharge sensor IR2, which is approximately two seconds under nominal operating conditions. A threshold comparator block checking whether the gap is greater than or equal to zero was also included to implement the conditional logic governing the asymmetric gain selection between braking and accelerating controller modes. The feedback signal is then routed back to the summing junction to close the control loop, and a scope block labeled "Gap" captures the inter-item gap response over time for analysis.

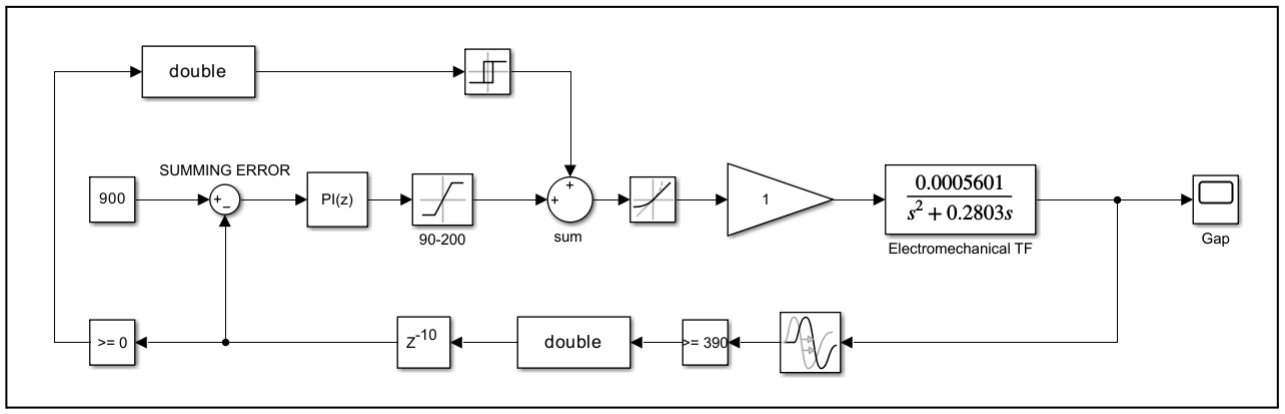
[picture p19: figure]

“figure 6.1. simulink simulation diagram”

Leading Innovations, Transforming Lives, Building the Nation page 57

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

Figure 6.2 shows the Simulink simulation output under ideal steady-state conditions where the inter-item gap converges to approximately 900 ms and remains stable throughout the simulation duration of approximately 18 seconds. The output trace exhibits a flat horizontal response near the setpoint value, confirming that under nominal conditions with items introduced at the target interval, the PI controller maintains the conveyor at its default PWM output of 110 with negligible corrective action required. This result validates that the model correctly implements steady-state behavior and that the controller does not introduce unnecessary oscillations when the system is operating at its desired operating point.

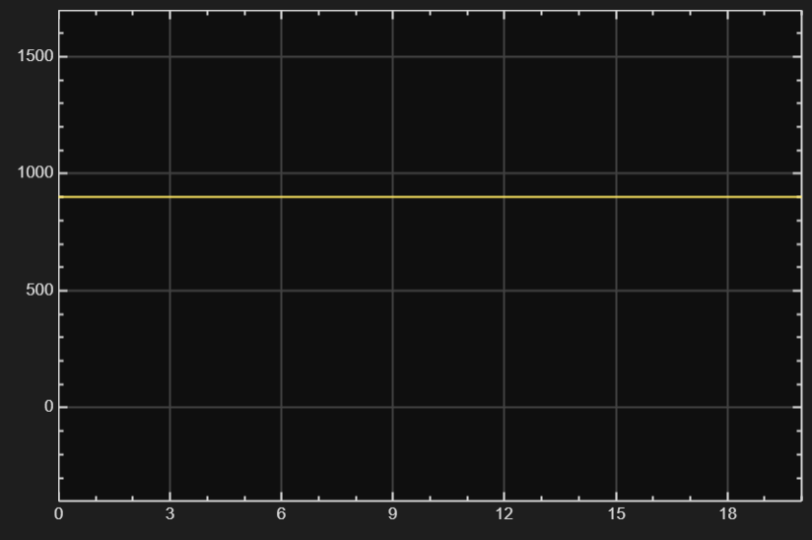
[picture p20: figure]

“figure 6.2. simulink diagram output”

Leading Innovations, Transforming Lives, Building the Nation page 58

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

MATLAB Digital Twin

Figure 6.3 presents the MATLAB Digital Twin interface developed to complement the Simulink model and serve as an interactive simulation environment that mirrors the physical conveyor prototype. The digital twin, designated as version 5, replicates the full system configuration including the conveyor belt visualization, dual IR sensor positions, real-time LCD display output, live PI signal plots, and an operator control panel. The interface displays real-time values for PWM output, inter-item gap in milliseconds, item count, and PI error, mirroring the data visible on the physical prototype's I2C LCD display. The control panel provides START, STOP, and RESET functions, as well as a manual mode toggle and an item injection button for simulating item entry at IR1. Adjustable slider controls for item spacing interval, Kp slow, Ki slow, Kp fast, and Ki fast allow the operator to tune the asymmetric PI gains interactively and observe the resulting system response in real time through the three live signal plots showing inter-item gap, PWM output, and PI error over a rolling 30-second window.

Leading Innovations, Transforming Lives, Building the Nation page 59

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

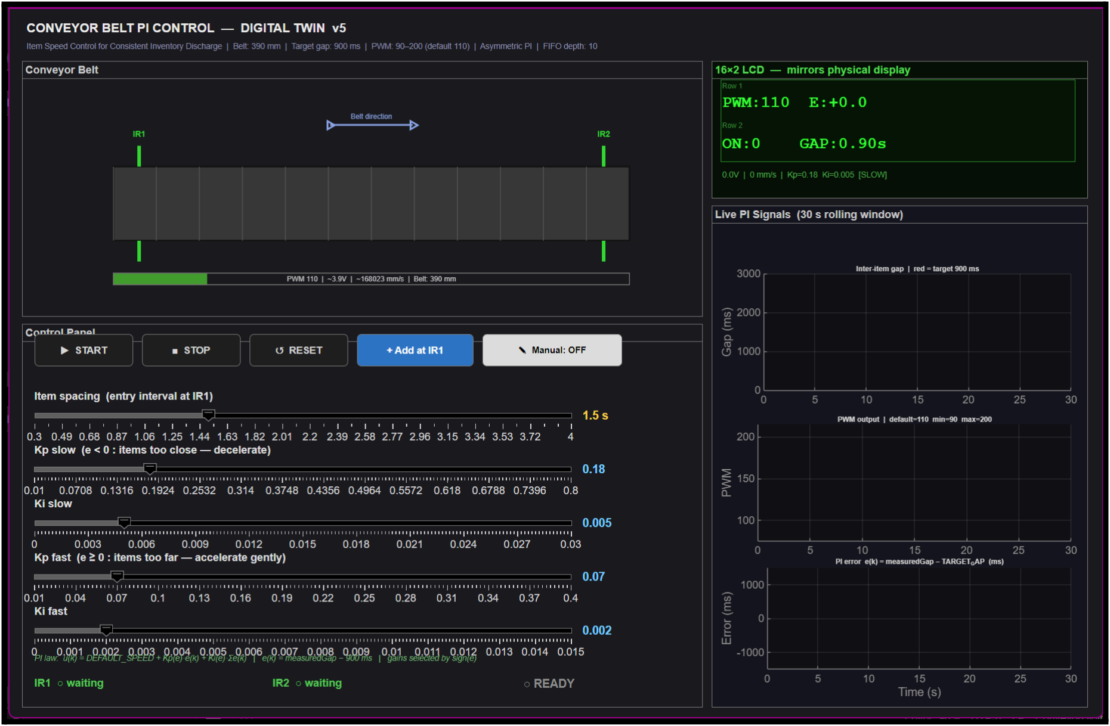
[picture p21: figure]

“figure 6.3.MatLab digital twin”

Figure 6.4 illustrates the digital twin operating in automatic mode under an ideal spacing condition where two items are placed on the belt at approximately the target gap interval of 900 ms. The LCD display panel on the right side of the interface shows a PWM value of 119 with an error of +1.0, an item count of 2, and a measured gap of 1.00 seconds. The live signal plots confirm stable gap tracking near the setpoint with minimal PWM variation and a near-zero error signal, demonstrating that the controller correctly maintains steady-state operation when items are introduced at the desired interval.

Leading Innovations, Transforming Lives, Building the Nation page 60

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

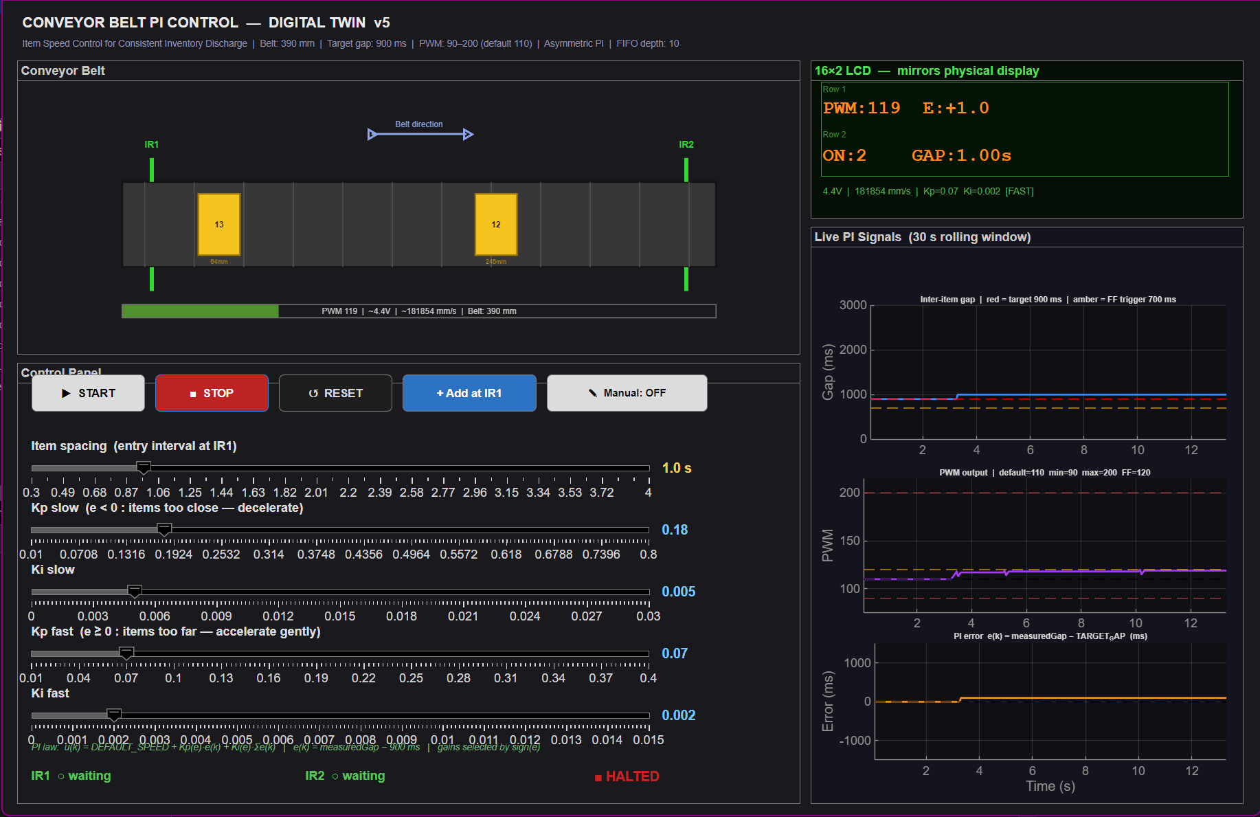
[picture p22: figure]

“figure 6.4. Matlab Digital twin auto mode (ideal state)”

Figure 6.5 shows the digital twin under the close-spacing scenario in manual mode, where two items are visible on the conveyor belt positioned closer together than the target threshold. This condition corresponds to a measured gap below 900 ms, triggering the braking gain set of Kp = 0.18 and Ki = 0.005. The conveyor belt visualization shows the items in close proximity, and the system is prepared to apply a speed reduction corrective response upon detection at IR2.

Leading Innovations, Transforming Lives, Building the Nation page 61

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

The accompanying graph data for the close scenario, shown in the figure labeled as the close scenario graph data, presents the time history of the inter-item gap, PWM output, and PI error over approximately six seconds. The gap plot shows the measured gap dipping below the 900 ms setpoint reference line before the PI controller reduces the PWM output, which is reflected in the PWM trace dropping below the default value of 110. The error plot confirms a corresponding negative error during the gap undershoot period, followed by recovery toward zero as the corrective action takes effect. The feed-forward trigger at 700 ms, represented by the amber reference line in the gap plot, is also visible, demonstrating the pre-emptive speed reduction mechanism activated when the entry gap is detected below the feed-forward threshold.

The far-spacing scenario shown in the subsequent digital twin figure presents the opposite condition, where two items are placed with a gap significantly exceeding the target interval. In this case the accelerating gain set of Kp = 0.07 and Ki = 0.002 is activated, and the PWM output increases above the default value to reduce the excessive discharge interval. The corresponding graph data for the far scenario shows the inter-item gap rising above the setpoint reference during the period of large spacing, with the PWM trace increasing above 110 in response. The error signal displays a positive deviation during this period before returning toward zero as the controller brings the gap back toward the 900 ms target. The settled response visible in the error plot confirms the integral action of the PI controller successfully eliminates steady-state offset under the far-spacing condition.

Leading Innovations, Transforming Lives, Building the Nation page 62

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

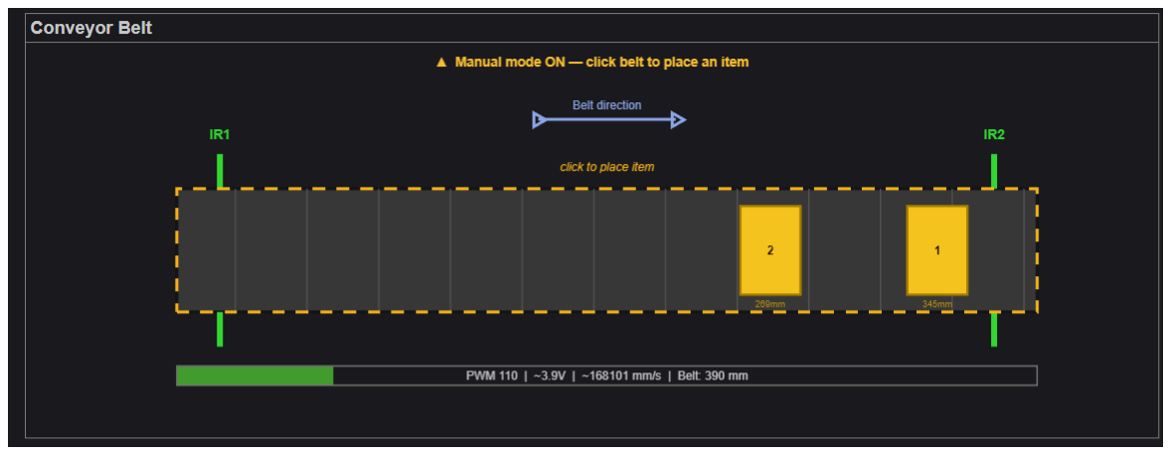
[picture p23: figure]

“figure 6.5. Matlab Digital twin (close scenario)”

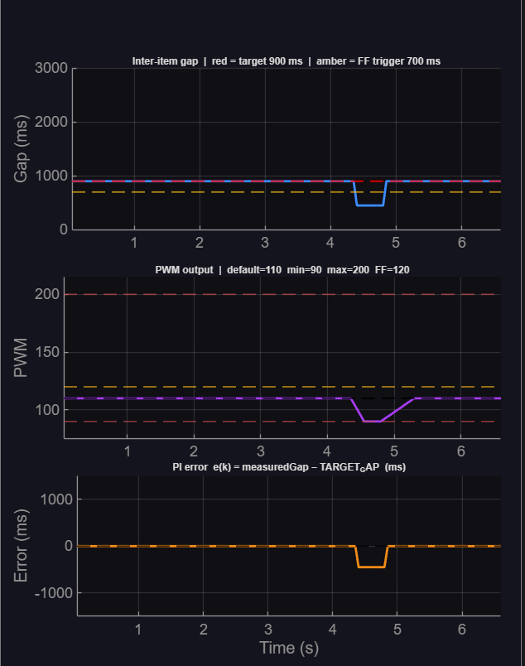
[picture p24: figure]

“figure 6.4. Matlab Digital twin close scenario graph data”

Leading Innovations, Transforming Lives, Building the Nation page 63

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

“figure 6.4. Matlab Digital twin far scenario”

“figure 6.4. Matlab Digital twin far scenario graph data” Leading Innovations, Transforming Lives, Building the Nation page 64

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

Controller Tuning

The PI controller implemented in this system employs an asymmetric gain structure rather than a conventional fixed-gain approach, reflecting the physically different dynamics encountered during deceleration and acceleration of the conveyor belt. Controller tuning was performed iteratively using the MATLAB Digital Twin interface, which allowed real-time observation of gap response, PWM output, and error signal behavior while adjusting gain values through the interactive sliders prior to flashing the parameters onto the Arduino firmware.

Two distinct gain sets were defined based on the sign of the error signal. When the measured gap falls below the 900 ms target, indicating items are too close together, the braking gain set of Kp = 0.18 and Ki = 0.005 is applied. The higher proportional gain in this configuration produces a stronger and faster speed reduction response, reflecting the greater urgency of preventing item congestion at the discharge region. When the measured gap exceeds the target, indicating items are too far apart, the accelerating gain set of Kp = 0.07 and Ki = 0.002 is engaged. The lower gain values in this configuration produce a gentler speed increase, avoiding overshoot during acceleration and preventing the belt from running excessively fast between corrections.

The default PWM output was set to 110, corresponding to an applied voltage of approximately 3.9 V to the DC gear motor and a nominal belt speed of approximately 168 mm per second under no-load conditions. The PWM output was clamped within the range of 90 to 200 to protect the motor from operating below its minimum effective speed threshold or exceeding its rated capacity. The integral term was bounded by a hard clamp of ±1000, limiting the maximum integral contribution to ±5 PWM units and preventing integral windup during sustained error conditions. Anti-windup was implemented through conditional integration, where

Leading Innovations, Transforming Lives, Building the Nation page 65

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

the integral accumulator is only updated when the controller output is not simultaneously saturated in the same direction as the error.

An asymmetric PWM ramp rate was also incorporated into the actuator model, where the conveyor decelerates at a rate of 5 PWM units per step while it accelerates at only 2 PWM units per step. This 2.5:1 deceleration-to-acceleration ratio prevents sudden item pile-up that could occur if the belt slowed too abruptly during a braking correction, ensuring smooth and controlled speed transitions throughout normal operation.

A feed-forward trigger mechanism was additionally implemented to address the approximately two-second transport delay between IR1 and IR2. When the entry gap detected at IR1 is less than 700 ms, a one-shot pre-emptive speed reduction to a PWM value of 120 is scheduled 1000 ms after the detection event, firing midway through the transport delay before the item reaches IR2. This Smith Predictor-inspired approach allows the system to begin corrective action earlier than the feedback loop alone would permit, reducing the effective impact of the transport delay on system response and improving overall discharge consistency.

### VII. Experimental / Prototype Testing

The prototype features a custom-designed 3D-printed conveyor system actuated by a TT DC gear motor. The motor drives the conveyor belt at an adjustable speed regulated by an L298N motor driver module, which accepts PWM signals to vary the output voltage supplied to the motor.

The system logic is programmed and executed on an Arduino Uno microcontroller, which interfaces with two infrared proximity sensors to implement closed-loop speed control. The first sensor, IR1, is positioned at the entry point of the conveyor and is responsible for detecting the Leading Innovations, Transforming Lives, Building the Nation page 66

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

arrival of incoming objects and recording the inter-item gap interval at the point of entry. The second sensor, IR2, is positioned near the discharge end of the belt and serves as the feedback point for the control system, triggering speed adjustments upon detecting each exiting item to maintain a consistent and uniform discharge rate.

To ensure that each speed correction applied at IR2 corresponds precisely to the gap measurement of the correct item, a First-In First-Out (FIFO) queue structure was implemented in firmware. Gap intervals recorded at IR1 are stored sequentially in the queue and retrieved in the same order as items arrive at IR2, preserving measurement-to-item correspondence even when multiple objects are in transit on the belt simultaneously. The queue supports a capacity of up to ten concurrent items.

Several protective measures are incorporated to ensure safe and reliable operation. Motor speed is bounded within a defined operational range, with a minimum PWM value of 90, a maximum of 200, and a default operating value of 110, preventing the motor from being driven below its minimum effective threshold or beyond its rated capacity. These constraints extend motor service life and reduce the risk of mechanical overload during transient control corrections.

To evaluate the performance of the prototype, three identical test objects in the form of cubes measuring 1.5 cm per side were used as the detection targets throughout all testing procedures. The cubes were introduced onto the entry ramp sequentially and detected by IR1 under four distinct test conditions, each designed to assess a specific aspect of the system's closed-loop speed control response.

The first test established a baseline by introducing the cubes at the target gap interval of 900 ms, representing the ideal spacing condition under which the system is expected to operate with minimal correction. The second test introduced the cubes at an interval below 900 ms, Leading Innovations, Transforming Lives, Building the Nation page 67

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

simulating an overcrowded entry condition in which items are spaced too closely, requiring the system to reduce belt speed in order to restore the target discharge gap. The third test introduced the cubes at an interval exceeding 900 ms, representing an underpopulated entry condition in which items are spaced too far apart, requiring the system to increase belt speed to recover the target gap. The fourth and final test combined both conditions simultaneously using all three cubes, where one pair of cubes was introduced with a gap below the target threshold and the other pair with a gap above it, evaluating the system's ability to handle mixed spacing conditions within a single batch and correctly apply independent corrections to each item through the FIFO queue.

### VIII. Results and Discussion

Analysis of System Performance

The developed prototype successfully demonstrated the implementation of closed-loop PI-based speed control for maintaining consistent object discharge spacing in a conveyor system. By integrating two infrared proximity sensors, an Arduino Uno microcontroller, and a FIFO queue structure, the system was able to monitor object intervals and apply corresponding speed corrections in real time. The prototype utilized a custom-designed 3D-printed conveyor actuated by a TT DC gear motor controlled through an L298N motor driver module. The conveyor speed was dynamically adjusted through PWM control signals generated by the Arduino Uno based on spacing feedback obtained from the infrared sensors. IR1 measured the incoming inter-item gap intervals, while IR2 acted as the feedback sensor responsible for triggering corrective actions near the discharge region of the conveyor. Experimental evaluation was conducted using three identical cubic test objects measuring 1.5 cm on each side. The system was tested under different

Leading Innovations, Transforming Lives, Building the Nation page 68

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

spacing conditions centered around the target discharge interval of 900 ms. The obtained results demonstrated that the controller could effectively compensate for both overcrowded and underpopulated conveyor conditions.

Test scenario | Initial Gap Condition | Controller Response | Conveyor Speed action | Observed System Behaviour
Small gap trial | Gap < 900 ms | Positive spacing correction | Conveyor speed reduced | Discharge spacing gradually increased toward target interval
Large gap trial | Gap > 900 ms | Negative spacing correction | Conveyor speed increased | Discharge spacing gradually decreased toward target interval

During the small-gap trial, the objects were introduced with intervals below the desired 900 ms set point, simulating an overcrowded conveyor condition. Once the reduced spacing was detected, the PI controller responded by decreasing the PWM output supplied to the DC gear motor. This reduced conveyor speed and increased the discharge interval between objects, helping prevent object congestion at the output region. The recorded step and impulse response graphs showed transient oscillations immediately after correction due to the proportional and integral actions of the controller. However, the system gradually stabilized and approached the target operating condition without instability.

Leading Innovations, Transforming Lives, Building the Nation page 69

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

In the large-gap trial, the objects were introduced with intervals exceeding the target spacing, representing delayed item flow conditions. Upon detection at IR2, the controller increased the PWM duty cycle to accelerate the conveyor belt. This reduced the excessive discharge delay between successive objects and allowed the measured spacing to move closer toward the target interval. The system exhibited faster transient response characteristics during acceleration due to the motor’s ability to increase speed more rapidly than decelerate under load conditions. Minor overshoot was observed during correction, but the system eventually settled toward steady-state operation. The implemented FIFO queue structure played a significant role in maintaining system reliability during testing. Since multiple objects could simultaneously occupy the conveyor, the queue ensured that each spacing measurement obtained at IR1 was correctly associated with its corresponding object upon arrival at IR2. This prevented incorrect speed corrections and maintained accurate closed-loop operation even under mixed spacing conditions.

Overall, the experimental results indicate that the developed prototype was capable of dynamically regulating conveyor discharge spacing using low-cost embedded hardware and infrared sensing technologies. The controller successfully performed bidirectional corrective actions by slowing the conveyor during overcrowded conditions and accelerating it during underpopulated conditions while maintaining stable system behavior.

Sources of Error

Although the prototype demonstrated successful closed-loop control operation, several factors introduced inaccuracies and limitations during experimentation. One significant source of error was the inherent response limitation of the TT DC gear motor. Due to motor inertia and mechanical lag, changes in conveyor speed were not instantaneous after PWM adjustments were

Leading Innovations, Transforming Lives, Building the Nation page 70

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

applied. This resulted in transient overshoot and oscillatory behavior within the time response graphs, particularly during sudden spacing corrections. Sensor-related limitations also contributed to system inaccuracies. The infrared proximity sensors were sensitive to object alignment, ambient lighting conditions, and object reflectivity. Slight variations in cube positioning or sensor detection timing occasionally produced inconsistent gap measurements, affecting the precision of the controller’s corrective response.

Mechanical inconsistencies within the 3D-printed conveyor structure introduced additional disturbances. Minor belt slippage, uneven belt tension, and friction between moving components could alter the effective conveyor speed independently of the controller output. These mechanical effects became more noticeable during rapid acceleration or deceleration conditions. Timing inaccuracies associated with the Arduino Uno microcontroller and software execution also contributed to measurement deviations. Since the controller relied on millisecond timing intervals and sequential program execution, small processing delays could accumulate during multi-object operation, especially when multiple queue operations and sensor detections occurred simultaneously.Another limitation was the simplified tuning of the PI controller gains. While the selected gain values produced stable operation, the controller was not fully optimized for all possible operating conditions. As a result, small steady-state errors and temporary oscillations remained present during system response. More advanced tuning methods or the implementation of additional derivative control could potentially improve transient response performance and reduce overshoot.

Despite these limitations, the prototype successfully demonstrated the feasibility of using closed-loop PI control for conveyor spacing regulation. The observed errors were generally minor and did not prevent the system from achieving its primary objective of maintaining a more consistent object discharge interval.

Leading Innovations, Transforming Lives, Building the Nation page 71

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

### IX. Conclusion

This project successfully designed, modeled, simulated, and physically implemented a closed-loop PI-based conveyor speed control system for consistent inventory discharge using infrared proximity sensors. Through the integration of mechatronics engineering principles spanning mechanical design, electronics, embedded programming, and control theory, the project demonstrated that a low-cost embedded system is capable of dynamically regulating conveyor belt speed to maintain a consistent inter-item discharge interval under varying input spacing conditions.

Summary of Findings

The mathematical modeling phase established transfer functions and state-space representations for each subsystem of the conveyor system, including the electrical circuit, translational mechanical assembly, rotational mechanical drivetrain, electromechanical motor model, and gear system. The dominant electromechanical transfer function of the form 0.0005601 / (s² + 0.2803s) was identified as the primary plant model governing motor shaft response to applied armature voltage. State-space matrices derived from the translational and rotational models further characterized the multi-degree-of-freedom dynamic behavior of the conveyor structure, confirming system stability and providing a foundation for controller design.

The asymmetric PI control law implemented in this system used separate gain sets for braking and accelerating conditions, with Kp = 0.18 and Ki = 0.005 applied during close-spacing corrections and Kp = 0.07 and Ki = 0.002 applied during far-spacing corrections. This asymmetric structure was motivated by the physically different urgency and dynamic characteristics of deceleration versus acceleration in the conveyor system. Anti-windup conditioning, PWM output clamping between 90 and 200, asymmetric ramp rates favoring faster Leading Innovations, Transforming Lives, Building the Nation page 72

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

deceleration over acceleration, and a feed-forward pre-compensation trigger were incorporated to improve robustness and reduce the impact of the approximately two-second belt transport delay. A FIFO queue structure implemented in firmware ensured accurate measurement-to-item correspondence when multiple objects simultaneously occupied the conveyor belt.

Time response analysis conducted through MATLAB simulation showed that the accelerating gain configuration produced faster rise time and quicker settling behavior, while the braking configuration exhibited larger overshoot and more pronounced oscillatory transients due to its higher proportional gain. The key performance metrics comparison confirmed that steady-state error under the accelerating condition was significantly lower than under the braking condition, and that both configurations successfully drove the inter-item gap toward the 900 ms target setpoint over time. The MATLAB digital twin validated these behaviors interactively prior to hardware testing and demonstrated reliable correspondence between simulated and physical system responses.

Prototype testing under four experimental conditions — ideal spacing, close spacing, far spacing, and mixed spacing — confirmed that the system performed bidirectional corrective actions correctly in all cases. During the small-gap trial, the controller reduced conveyor speed and gradually increased the discharge interval toward the target. During the large-gap trial, the controller increased belt speed and reduced the excessive discharge delay. The FIFO queue successfully maintained correct correction-to-item pairing during the mixed-spacing trial involving multiple objects with different gap conditions simultaneously on the belt. Despite the presence of minor oscillatory transients, mechanical disturbances, and sensor variability, the system consistently achieved its primary objective of maintaining a more uniform discharge interval compared to uncontrolled operation.

Leading Innovations, Transforming Lives, Building the Nation page 73

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

Effectiveness of Closed-Loop Control

The results of this project affirm that closed-loop control is essential for achieving reliable and adaptive conveyor operation. Unlike open-loop systems that operate at a fixed speed regardless of actual item conditions, the closed-loop architecture employed here continuously monitors real-time spacing feedback and applies corrective action only when deviation from the setpoint is detected. This feedback-driven approach allowed the system to compensate for variable item introduction rates, mechanical inconsistencies, and transient disturbances without requiring manual intervention. The integral action of the PI controller further ensured that residual steady-state errors were minimized over successive correction cycles, improving the overall consistency of discharge spacing across extended operation. The asymmetric gain design and feed-forward compensation demonstrated that purposeful controller customization beyond standard fixed-gain tuning can meaningfully improve performance in systems with asymmetric physical dynamics and significant transport delay.

Industrial Relevance

The principles demonstrated in this project are directly applicable to industrial-scale conveyor automation systems used in manufacturing plants, packaging facilities, warehouses, and distribution centers. In production environments where downstream stations such as robotic arms, packaging machines, labeling equipment, or human operators depend on a predictable and consistent product arrival rate, irregular conveyor discharge can cause congestion, processing delays, equipment overload, and safety risks. The closed-loop speed control approach demonstrated here addresses these challenges by automatically regulating item flow based on real-time sensor feedback, eliminating the need for fixed-speed operation and reducing the likelihood of bottlenecks or gaps in the production stream.

Leading Innovations, Transforming Lives, Building the Nation page 74

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

Furthermore, the low-cost bill of materials totaling approximately PHP 3,946.00, the use of commercially available embedded hardware, and the modular 3D-printed mechanical design demonstrate that effective closed-loop conveyor control need not require expensive industrial programmable logic controllers or proprietary automation hardware. This makes the system concept accessible for small-to-medium scale manufacturing operations and educational demonstrations of industrial automation principles. Future work may explore the integration of a full PID controller with derivative action to further reduce transient overshoot, the use of encoder-based speed feedback to improve motor control precision, and the scaling of the system to handle heavier loads and longer belt configurations representative of real industrial conveyor environments.

Leading Innovations, Transforming Lives, Building the Nation page 75

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

### X. Documentation

BILL OF MATERIALS

Item | Description | Qty . | Unit Price (PHP) | Price (PHP)
DC motor | TT Gear Motor | 1 | 49.00 | 49.00
IR Sensor | HW 201 Infra-Red Proximity sensor | 2 | 49.00 | 98.00
L298N | Stepper motor drive controller board module | 1 | 99.00 | 99.00
Switching Power Supply | 230V AC to 12V 5A DC converter | 1 | 309.00 | 309.00
LCD Display with I2c connector | Display to monitor the system real-time | 1 | 149.00 | 149.00
LM2596 | Step-Down Adjustable DC-DC Switching Buck converter | 1 | 55.00 | 55.00
Arduino Uno R3 | Primary Controller | 1 | 449.00 | 449.00
Sensor Shield v5 for arduino | Provides additional VCC and GND pins | 1 | 99.00 | 99.00

Leading Innovations, Transforming Lives, Building the Nation page 76

Alangilan Campus
Golden Country Homes, Alangilan Batangas City, Batangas, Philippines 4200
Tel Nos.: (+63 43) 425-0139 local 2121 / 2221
E-mail Address: coe.alangilan@g.batstate-u.edu.ph | Website Address: http://www.batstate-u.edu.ph (http://www.batstateu-u.edu.ph)
College of Engineering - Department of Electronics Engineering Bachelor of Science in Mechatronics Engineering
1kg 3D Printing Filament PETG | (Polyethylene Terephthalate Glycol) 1.75mm 3D Printing Filament. | 1 | 483.00 | 483.00
(Small) MTS102 toggle switch | Serves as the toggle switch for system power | 1 | 25.00 | 25.00
Push Button with Micro Switch | One Red and One Green | 2 | 26.00 | 52.00
Waterproof plastic case | 100x68x50mm Outdoor Waterproof Case Enclosure Plastic Box Electronic Project Junction | 1 | 99.00 | 99.00
Plywood | 300x600x10mm plywood | 1 | 230.00 | 230.00
Additive manufacturing cost (527.73g | | | | 1,750.00
Total Cost | | | | 3,946.00

Leading Innovations, Transforming Lives, Building the Nation page 77

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

“top view prototype”

“front view prototype”
Leading Innovations, Transforming Lives, Building the Nation page 78

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

### X. References

Deka, R., Borthakur, P. P., Baruah, E., Sarmah, P., & Saikia, M. (2024). A comprehensive review on mechanical conveyor systems: Evolution, types, and applications. International Journal of Natural and Engineering Sciences, 18(3), 164–183.

Lastname, F. (Year). Automated control system: Selection, design and programming of automated control system for a conveyor belt in fishing industry [Unpublished undergraduate thesis]. [University name]. http://hdl.handle.net/1946/19741

Thienyaem, T., Saengprachatanarug, K., Ueno, M., & Taira, E. (2016). Analysis of discharge consistency and performance of a sugarcane billet planter with a side-conveyer concept. KKU Engineering Journal, 43(1), 9–12.

Leading Innovations, Transforming Lives, Building the Nation page 79

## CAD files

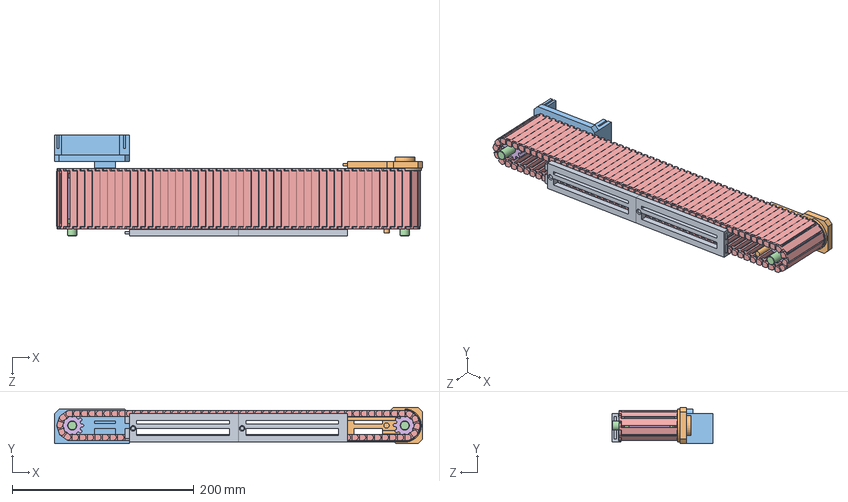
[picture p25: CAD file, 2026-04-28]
3D Printed Conveyor/CONVEYOR assembly.SLDASM
405.0 x 40.0 x 111.0 mm
BELT GEAR x 2
belt x 98
Bearing Couple key x 3
DC Motor Chassis
Conveyor Frame Corner Male 1 with support connector
Conveyor Frame x 2

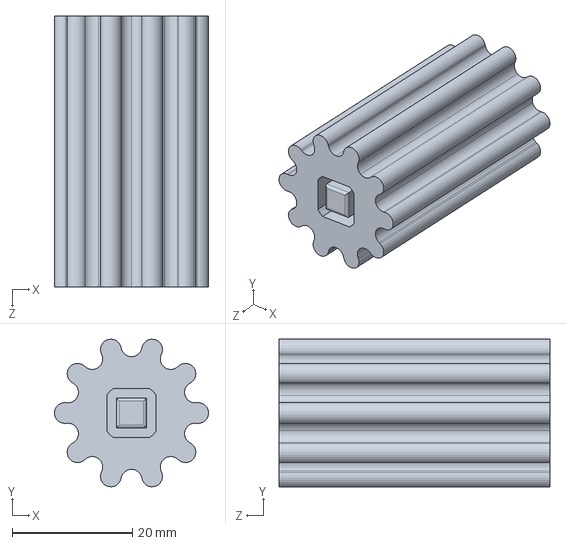
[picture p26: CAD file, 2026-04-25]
3D Printed Conveyor/Electro-Mechanical design/BELT GEAR.SLDPRT
25.6 x 24.5 x 45.0 mm

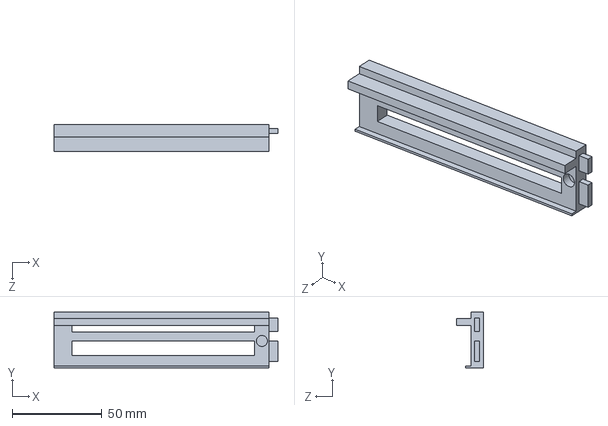
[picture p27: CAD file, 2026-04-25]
3D Printed Conveyor/Frame /Conveyor Frame.SLDPRT
125.0 x 31.2 x 15.0 mm

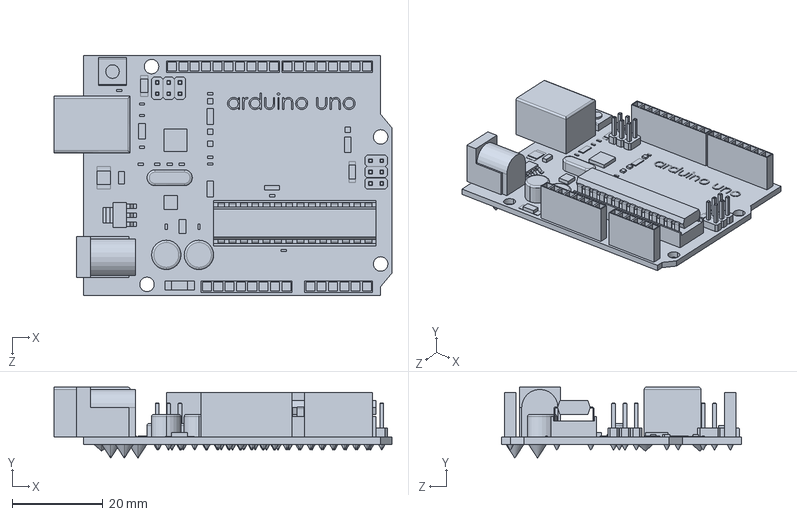
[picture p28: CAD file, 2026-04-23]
ELECTRONICS/Arduino_Uno.step.SLDPRT
74.5 x 15.6 x 53.0 mm

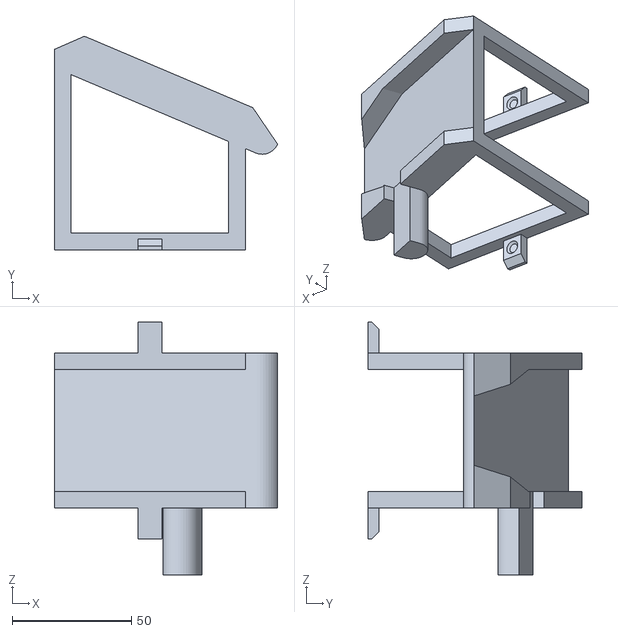
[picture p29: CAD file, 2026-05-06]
ramp.STL
93.5 x 89.5 x 106.0

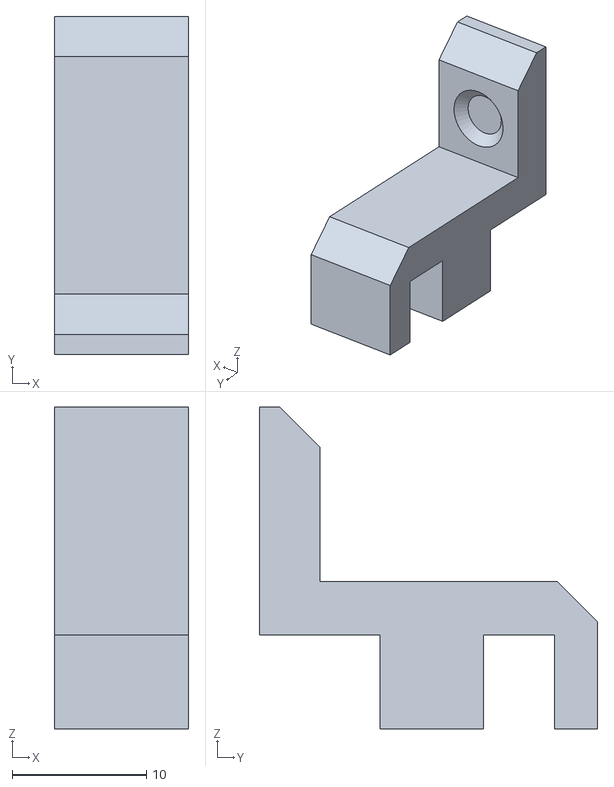
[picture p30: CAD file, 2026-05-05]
supports/conveyor support piecex4.STL
10.0 x 25.2 x 24.0

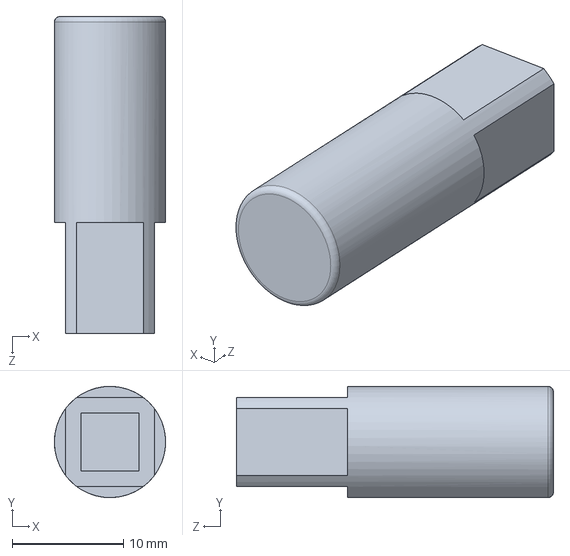
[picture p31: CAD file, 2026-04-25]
3D Printed Conveyor/Electro-Mechanical design/Bearing Couple key.SLDPRT
10.0 x 10.0 x 28.5 mm

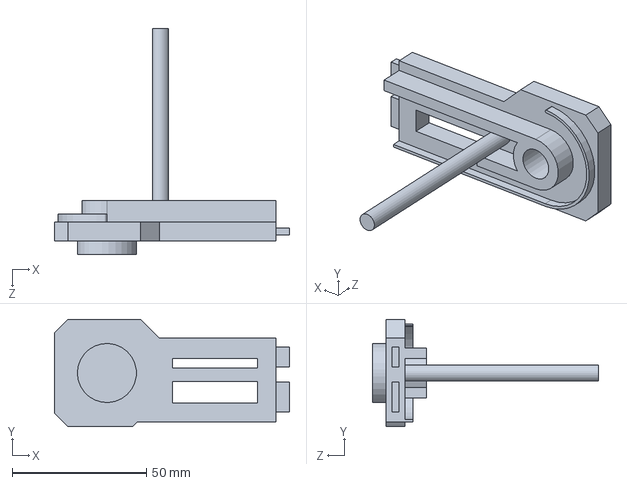
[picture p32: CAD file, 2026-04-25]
3D Printed Conveyor/Frame /Conveyor Frame Corner Male 1 with support connector.SLDPRT
87.5 x 40.0 x 84.0 mm

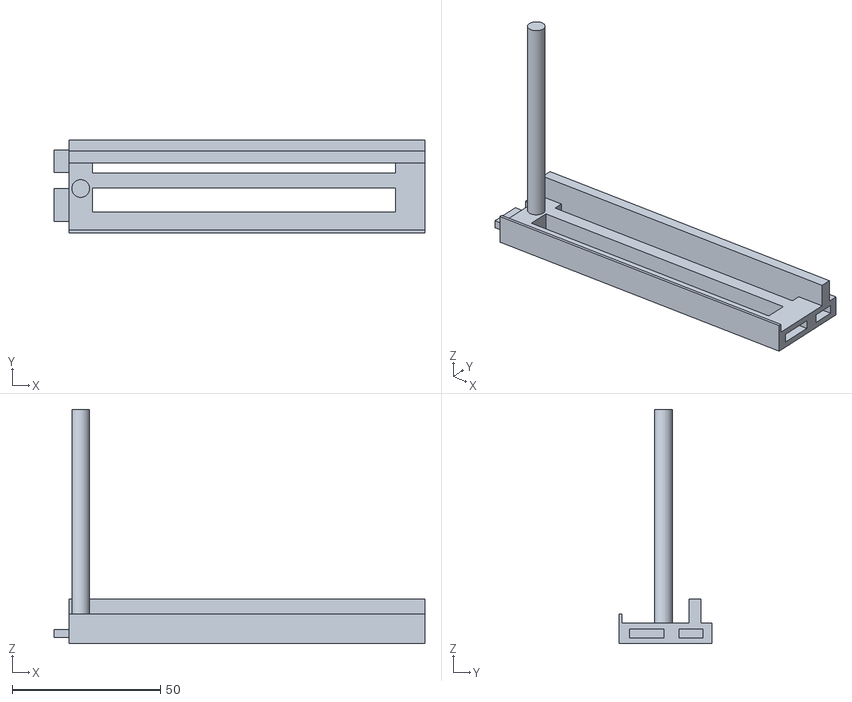
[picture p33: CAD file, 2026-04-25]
3D Printed Conveyor/STL Files/Conveyor Frame with support connector.STL
125.0 x 31.2 x 79.0

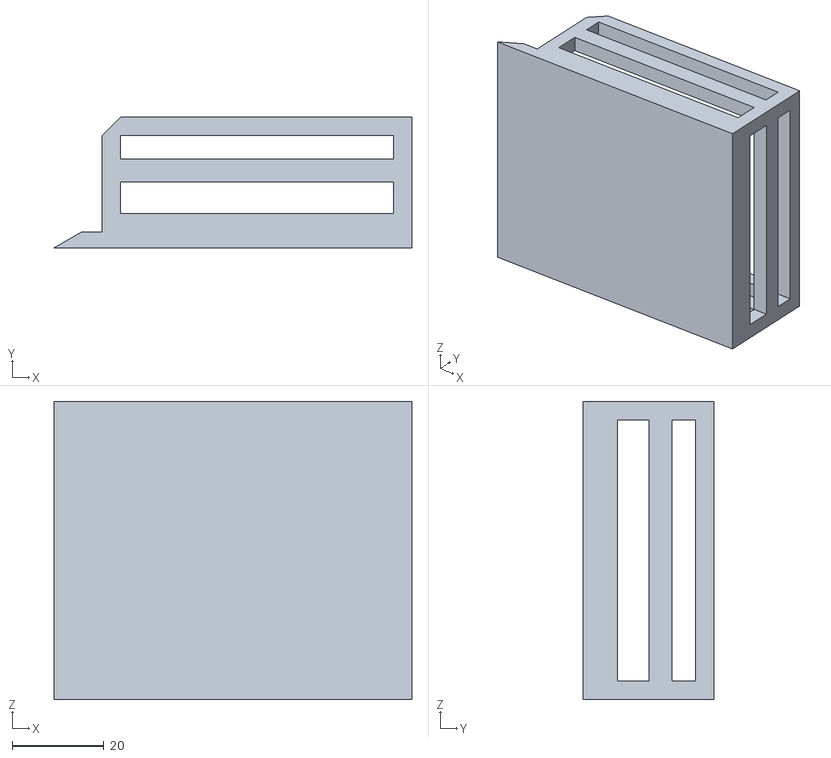
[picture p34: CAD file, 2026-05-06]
basket.STL
78.1 x 28.5 x 65.0

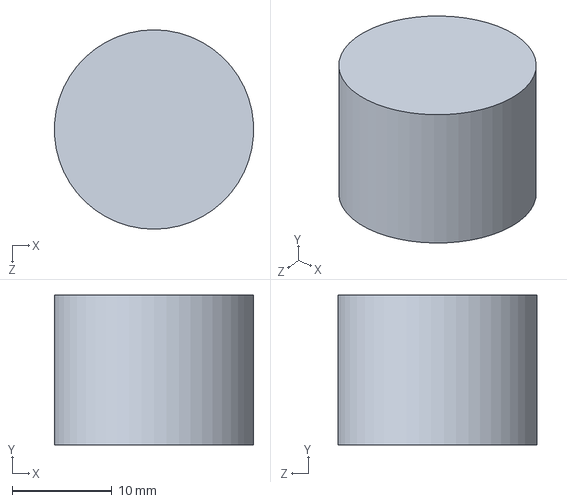
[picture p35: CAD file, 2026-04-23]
ELECTRONICS/pb red.SLDPRT
20.0 x 15.0 x 20.0 mm

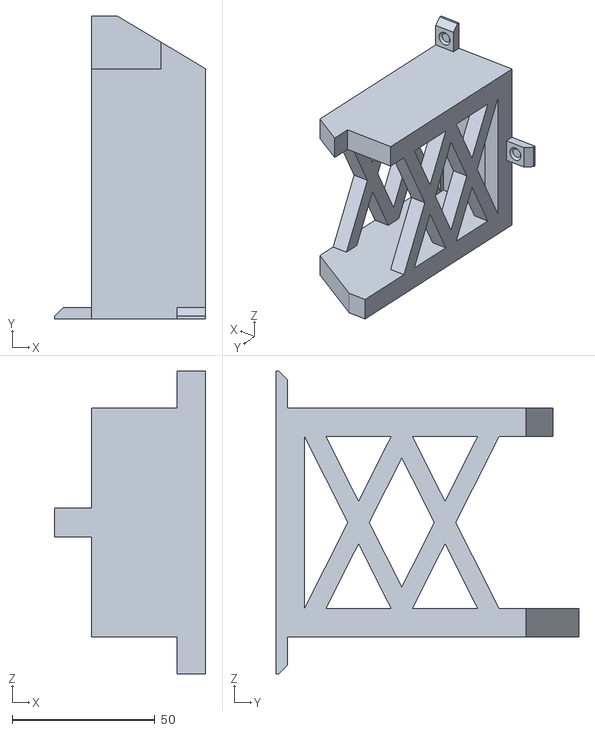
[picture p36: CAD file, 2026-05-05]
supports/lcd standx1.STL
52.9 x 106.0 x 106.0

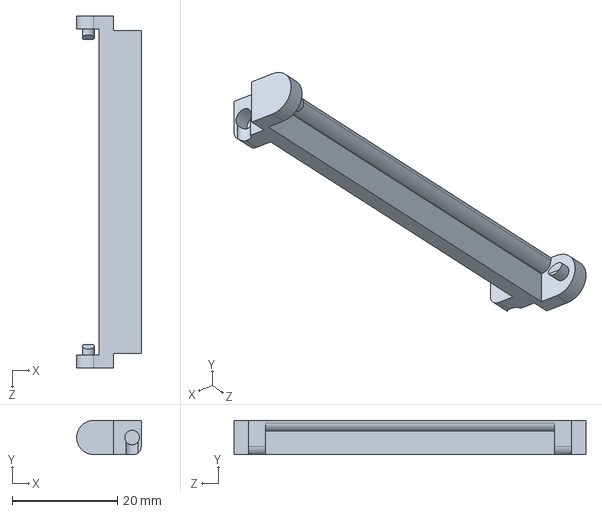
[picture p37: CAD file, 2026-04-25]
3D Printed Conveyor/Electro-Mechanical design/belt.SLDPRT
12.3 x 6.50 x 67.0 mm

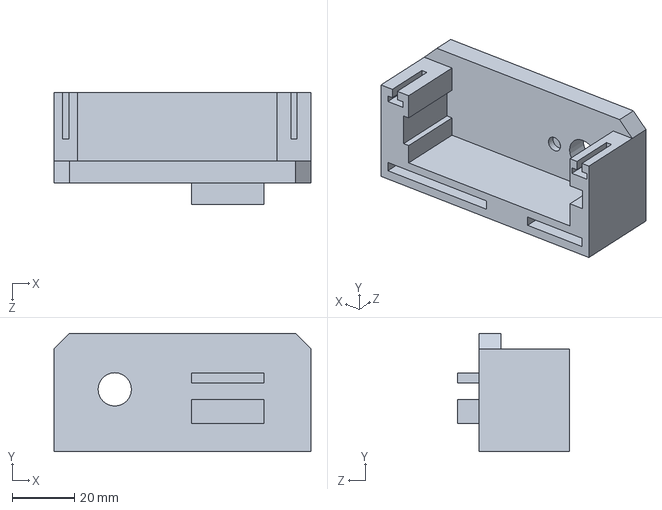
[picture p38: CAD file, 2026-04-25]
3D Printed Conveyor/Frame /DC Motor Chassis.SLDPRT
82.5 x 38.0 x 36.0 mm

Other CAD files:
375 ml Australian can RED.SLDASM
3D Printed Conveyor/STL Files/Conveyor Frame.STL
3D Printed Conveyor/STL Files/Motor Prime Mover Key couple.STL
sensor mount.STL
3D Printed Conveyor/Electro-Mechanical design/Motor Prime Mover Key couple.SLDPRT
3D Printed Conveyor/Electro-Mechanical design/MotorGear01.SLDPRT
3D Printed Conveyor/Frame /Conveyor Corner Frame with Motor Coupling slot.SLDPRT
3D Printed Conveyor/Frame /Conveyor Frame corner female 1.SLDPRT
3D Printed Conveyor/Frame /Conveyor Frame with support connector.SLDPRT
3D Printed Conveyor/Frame /Conveyor frame corner male 2.SLDPRT
3D Printed Conveyor/Frame /DC Motor Chassis Cover.SLDPRT
3D Printed Conveyor/STL Files/BELT GEAR.STL
3D Printed Conveyor/STL Files/Bearing Couple key.STL
3D Printed Conveyor/STL Files/Conveyor Corner Frame with Motor Coupling slot.STL
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

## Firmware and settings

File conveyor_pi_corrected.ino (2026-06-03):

#include <Wire.h>
#include <LiquidCrystal_I2C.h>

// ============================================================
// LCD SETUP
// ============================================================
LiquidCrystal_I2C lcd(0x27, 16, 2);

// ============================================================
// IR SENSOR PINS
// ============================================================
const int IR_SENSOR_1 = 2;   // ENTRY SENSOR
const int IR_SENSOR_2 = 3;   // EXIT SENSOR

// ============================================================
// MOTOR DRIVER (L298N)
// ============================================================
const int motor1pin1 = 6;
const int motor1pin2 = 7;
const int ENA        = 5;

// ============================================================
// PUSH BUTTONS
// ============================================================
const int GREEN_BTN = 8;
const int RED_BTN   = 9;

// ============================================================
// SPEED SETTINGS
// ============================================================
const int DEFAULT_SPEED = 110;
const int MIN_SPEED     = 90;
const int MAX_SPEED     = 200;

// ============================================================
// TARGET GAP
// 900 ms limits belt occupancy to ~2 items at a time,
// giving IR2 corrections time to propagate before the next
// item commits to the belt.
// ============================================================
const unsigned long TARGET_GAP = 900; // milliseconds

// ============================================================
// FEED-FORWARD SCHEDULE
//
// When IR1 detects a dangerously small gap it schedules a
// soft pre-emptive speed reduction to fire midway through
// the belt travel (~1 second later). IR2 always overrides
// this with PI output when the item actually exits.
//
// FF_TRIGGER_GAP  — gap below this arms a feed-forward event
// FF_DELAY_MS     — how long after IR1 to fire (~half travel)
// FF_TARGET_PWM   — soft preliminary target PWM
// ============================================================
const unsigned long FF_TRIGGER_GAP = 700;  // ms
const unsigned long FF_DELAY_MS    = 1000; // ms
const int           FF_TARGET_PWM  = 120;  // soft pre-emptive target

// ============================================================
// PI CONTROLLER — ASYMMETRIC GAINS
//
// Reduced Ki (was 0.025 / 0.010) to prevent integral windup
// on this short 2-second transport delay belt.
// Max integral contribution = Ki * clamp = 0.005*1000 = ±5 PWM.
// Kp does the heavy lifting; I only removes residual bias.
// ============================================================
float Kp_slow = 0.18;
float Ki_slow = 0.005;

float Kp_fast = 0.07;
float Ki_fast = 0.002;

float integral = 0;

// ============================================================
// SYSTEM VARIABLES
// ============================================================
bool systemActive = false;

int currentPWM = DEFAULT_SPEED;
int targetPWM  = DEFAULT_SPEED;

int materialCount = 0;

// ============================================================
// SENSOR STATES
// ============================================================
bool lastIR1State   = HIGH;
bool lastIR2State   = HIGH;
bool lastGreenState = HIGH;
bool lastRedState   = HIGH;

// ============================================================
// TIMERS
// ============================================================
unsigned long previousEntryTime = 0;   // timestamp of last IR1 trigger
unsigned long entryGap          = 0;   // gap measured at IR1
unsigned long measuredGap       = 0;   // gap dequeued at IR2 for display
unsigned long lastLCDUpdate     = 0;

// ============================================================
// DEBOUNCE
// ============================================================
unsigned long lastIR1Debounce = 0;
unsigned long lastIR2Debounce = 0;
const unsigned long DEBOUNCE_DELAY = 120;

// ============================================================
// ENTRY GAP FIFO QUEUE
//
// IR1 enqueues each measured inter-item gap.
// IR2 dequeues the matching gap when an item exits.
//
// SEMANTICS NOTE: The queue holds N-1 gaps for N items per
// batch. The last item to exit will always dequeue the
// TARGET_GAP fallback, causing zero error — correct behaviour.
// ============================================================
const int QUEUE_SIZE = 10;
unsigned long gapQueue[QUEUE_SIZE];
int queueHead  = 0;
int queueTail  = 0;
int queueCount = 0;

void enqueueGap(unsigned long gap) {
  if (queueCount < QUEUE_SIZE) {
    gapQueue[queueTail] = gap;
    queueTail = (queueTail + 1) % QUEUE_SIZE;
    queueCount++;
  }
}

unsigned long dequeueGap() {
  if (queueCount > 0) {
    unsigned long gap = gapQueue[queueHead];
    queueHead = (queueHead + 1) % QUEUE_SIZE;
    queueCount--;
    return gap;
  }
  return TARGET_GAP; // fallback — last item of batch, no correction needed
}

// ============================================================
// FEED-FORWARD EVENT QUEUE
//
// Each entry records:
//   fireAt  — millis() timestamp when the event should execute
//   pwm     — the preliminary targetPWM to apply
//   active  — whether this slot is occupied
//
// IR1 populates slots; loop() fires them on schedule.
// IR2 cancels the matching slot before applying PI, ensuring
// PI always has final authority over feed-forward.
// ============================================================
const int FF_QUEUE_SIZE = 10;

struct FFEvent {
  unsigned long fireAt;
  int           pwm;
  bool          active;
};

FFEvent ffQueue[FF_QUEUE_SIZE];
int ffCount = 0;

void scheduleFFEvent(unsigned long delayMs, int pwm) {
  for (int i = 0; i < FF_QUEUE_SIZE; i++) {
    if (!ffQueue[i].active) {
      ffQueue[i].fireAt = millis() + delayMs;
      ffQueue[i].pwm    = pwm;
      ffQueue[i].active = true;
      ffCount++;
      return;
    }
  }
  // All slots full — drop silently (belt saturated)
}

// Called every loop() iteration — fires any due events.
// Only lowers speed, never raises it.
void processFFEvents() {
  unsigned long now = millis();
  for (int i = 0; i < FF_QUEUE_SIZE; i++) {
    if (ffQueue[i].active && now >= ffQueue[i].fireAt) {
      if (ffQueue[i].pwm < targetPWM) {
        targetPWM = ffQueue[i].pwm;
      }
      ffQueue[i].active = false;
      ffCount--;
    }
  }
}

// IR2 cancels the oldest pending FF event before applying PI,
// so PI output is never immediately overwritten by a late FF.
void cancelNextFFEvent() {
  unsigned long earliest = 0xFFFFFFFF;
  int           slot     = -1;

  for (int i = 0; i < FF_QUEUE_SIZE; i++) {
    if (ffQueue[i].active && ffQueue[i].fireAt < earliest) {
      earliest = ffQueue[i].fireAt;
      slot     = i;
    }
  }

  if (slot >= 0) {
    ffQueue[slot].active = false;
    ffCount--;
  }
}

void clearAllFFEvents() {
  for (int i = 0; i < FF_QUEUE_SIZE; i++) {
    ffQueue[i].active = false;
  }
  ffCount = 0;
}

// ============================================================
// MOTOR FUNCTIONS
// ============================================================
void motorRun(int pwmValue) {
  pwmValue = constrain(pwmValue, MIN_SPEED, MAX_SPEED);

  // Asymmetric ramp: faster slowdown, gentler speedup
  if (currentPWM > pwmValue)      currentPWM -= 5;
  else if (currentPWM < pwmValue) currentPWM += 2;

  currentPWM = constrain(currentPWM, MIN_SPEED, MAX_SPEED);

  analogWrite(ENA, currentPWM);
  digitalWrite(motor1pin1, HIGH);
  digitalWrite(motor1pin2, LOW);
}

void motorStop() {
  analogWrite(ENA, 0);
  digitalWrite(motor1pin1, LOW);
  digitalWrite(motor1pin2, LOW);
}

// ============================================================
// LCD FUNCTIONS
// ============================================================
void updateLCDReady() {
  lcd.clear();
  lcd.setCursor(0, 0); lcd.print("PI CONVEYOR");
  lcd.setCursor(0, 1); lcd.print("PRESS GREEN");
}

void updateLCDStopped() {
  lcd.clear();
  lcd.setCursor(0, 0); lcd.print("SYSTEM STOP");
  lcd.setCursor(0, 1); lcd.print("PRESS GREEN");
}

void updateLCDLive() {
  long errorMs    = (long)measuredGap - (long)TARGET_GAP;
  int  errorTenth = (int)(errorMs / 100);
  char errorSign  = (errorTenth >= 0) ? '+' : '-';
  int  errorAbs   = abs(errorTenth);

  char row0[17];
  snprintf(row0, sizeof(row0),
    "PWM:%-3d E:%c%d.%d",
    currentPWM, errorSign, errorAbs / 10, errorAbs % 10
  );
  lcd.setCursor(0, 0);
  lcd.print(row0);

  unsigned int gapTenth = (unsigned int)(measuredGap / 100);
  char row1[17];
  snprintf(row1, sizeof(row1),
    "ON:%-2d GAP:%d.%d  ",
    materialCount, gapTenth / 10, gapTenth % 10
  );
  lcd.setCursor(0, 1);
  lcd.print(row1);
}

// ============================================================
// RESET SYSTEM
// ============================================================
void resetSystem() {
  materialCount     = 0;
  previousEntryTime = 0;   // FIX: cleared so inter-batch gaps are not measured
  entryGap          = 0;
  measuredGap       = 0;
  targetPWM         = DEFAULT_SPEED;
  currentPWM        = DEFAULT_SPEED;
  integral          = 0;

  queueHead  = 0;
  queueTail  = 0;
  queueCount = 0;

  clearAllFFEvents();
}

// ============================================================
// PI SPEED CONTROL — EVENT-DRIVEN, ANTI-WINDUP
//
// Called ONLY from IR2 block (once per item exit).
//
// Key properties:
//   - Integral updates once per item exit, NOT every loop tick
//   - Conditional integration: skips accumulation when output
//     is saturated AND error would push it further into sat.
//   - Integral clamped to ±1000 → max I contribution ±5 PWM
//   - Asymmetric gains: harder brake, gentler accelerate
//   - Kp does the heavy lifting on a 2-sec transport delay belt
//   - Ki only removes residual steady-state bias
// ============================================================
void applyPIControl() {
  float error = (float)measuredGap - (float)TARGET_GAP;

  // Select asymmetric gains
  // Negative error → items too close → slow down harder
  // Positive error → items too far   → speed up gently
  float Kp = (error < 0) ? Kp_slow : Kp_fast;
  float Ki = (error < 0) ? Ki_slow : Ki_fast;

  // Compute candidate output using CURRENT integral (before update)
  // so we can inspect saturation before touching the integral state.
  float pTerm     = Kp * error;
  float iTerm     = Ki * integral;
  int   candidate = DEFAULT_SPEED + (int)(pTerm + iTerm);

  // Conditional integration — anti-windup back-calculation guard:
  // Do NOT accumulate if the output is already railed AND the new
  // error would push it further into saturation.
  //   atMin + negative error → integrating would keep us floored
  //   atMax + positive error → integrating would keep us ceilinged
  bool atMin       = (candidate <= MIN_SPEED);
  bool atMax       = (candidate >= MAX_SPEED);
  bool windingWorse = (error < 0 && atMin) || (error > 0 && atMax);

  if (!windingWorse) {
    integral += error;
    integral  = constrain(integral, -1000.0f, 1000.0f); // tight clamp
  }

  // Recompute final output with updated integral
  iTerm     = Ki * integral;
  targetPWM = DEFAULT_SPEED + (int)(pTerm + iTerm);
  targetPWM = constrain(targetPWM, MIN_SPEED, MAX_SPEED);
}

// ============================================================
// SETUP
// ============================================================
void setup() {
  pinMode(IR_SENSOR_1, INPUT);
  pinMode(IR_SENSOR_2, INPUT);

  pinMode(motor1pin1, OUTPUT);
  pinMode(motor1pin2, OUTPUT);
  pinMode(ENA, OUTPUT);

  pinMode(GREEN_BTN, INPUT_PULLUP);
  pinMode(RED_BTN,   INPUT_PULLUP);

  lcd.init();
  lcd.backlight();

  motorStop();
  updateLCDReady();
}

// ============================================================
// MAIN LOOP
// ============================================================
void loop() {
  unsigned long now = millis();

  // ==========================================================
  // GREEN BUTTON (START)
  // ==========================================================
  bool greenState = digitalRead(GREEN_BTN);
  if (lastGreenState == HIGH && greenState == LOW) {
    delay(50);
    if (!systemActive) {
      systemActive = true;
      resetSystem();
      lcd.clear();
    }
  }
  lastGreenState = greenState;

  // ==========================================================
  // RED BUTTON (STOP)
  // ==========================================================
  bool redState = digitalRead(RED_BTN);
  if (lastRedState == HIGH && redState == LOW) {
    delay(50);
    systemActive = false;
    motorStop();
    resetSystem();
    updateLCDStopped();
  }
  lastRedState = redState;

  // ==========================================================
  // MAIN SYSTEM
  // ==========================================================
  if (systemActive) {

    // ========================================================
    // IR1 — ENTRY DETECTION
    //
    // Responsibilities:
    //   1. Increment materialCount
    //   2. Measure entryGap (only if a preceding item is still
    //      on the belt — materialCount > 1 after increment,
    //      AND previousEntryTime is valid)
    //   3. Enqueue entryGap (for IR2 PI use)
    //   4. If gap is dangerously small, SCHEDULE a FF event
    //
    // FIX: Gap is only measured and enqueued when materialCount
    // was already >= 1 before this item arrived (i.e. there is
    // a real preceding item on the belt). This prevents phantom
    // inter-batch gaps from polluting the queue when the belt
    // was empty between batches.
    //
    // IR1 never writes targetPWM, never calls applyPIControl().
    // ========================================================
    bool ir1State = digitalRead(IR_SENSOR_1);

    if (lastIR1State == HIGH &&
        ir1State == LOW &&
        now - lastIR1Debounce > DEBOUNCE_DELAY) {

      lastIR1Debounce = now;

      // Capture count BEFORE incrementing to check if a
      // preceding item is genuinely present on the belt.
      int countBeforeEntry = materialCount;
      materialCount++;

      // Only measure and act on a gap if:
      //   (a) previousEntryTime is set (not the very first item ever), AND
      //   (b) there was already at least 1 item on the belt
      //       (countBeforeEntry >= 1), meaning the gap is a real
      //       intra-batch gap, not a cross-batch measurement.
      if (previousEntryTime > 0 && countBeforeEntry >= 1) {
        entryGap = now - previousEntryTime;
        enqueueGap(entryGap);

        // If the gap is dangerously small, schedule a soft
        // pre-emptive slowdown to fire midway through belt travel.
        // IR2 will cancel this and replace with PI output.
        if (entryGap < FF_TRIGGER_GAP) {
          scheduleFFEvent(FF_DELAY_MS, FF_TARGET_PWM);
        }
      }

      previousEntryTime = now;
    }

    lastIR1State = ir1State;

    // ========================================================
    // TIMED FEED-FORWARD EVENTS
    //
    // Fires any FF events whose scheduled time has arrived.
    // Only lowers speed, never raises it.
    // IR2 always cancels the matching event before applying PI.
    // ========================================================
    processFFEvents();

    // ========================================================
    // IR2 — EXIT DETECTION
    //
    // Responsibilities:
    //   1. Decrement materialCount
    //   2. Cancel the feed-forward event for this item
    //   3. Dequeue the stored gap for this item
    //   4. Run PI control → update targetPWM
    //
    // IR2 is the ONLY place that calls applyPIControl().
    // PI output always overrides any prior feed-forward target.
    // ========================================================
    bool ir2State = digitalRead(IR_SENSOR_2);

    if (lastIR2State == HIGH &&
        ir2State == LOW &&
        now - lastIR2Debounce > DEBOUNCE_DELAY) {

      lastIR2Debounce = now;

      materialCount--;
      if (materialCount < 0) materialCount = 0;

      // Cancel matching scheduled FF before PI runs, so a
      // late-firing FF cannot overwrite fresh PI output.
      cancelNextFFEvent();

      // Retrieve the gap measured at IR1 for this item.
      // If queue is empty (last item of batch), returns TARGET_GAP
      // → error = 0 → no spurious correction.
      measuredGap = dequeueGap();
      applyPIControl();
    }

    lastIR2State = ir2State;

    // ========================================================
    // NO ITEMS ON BELT → RETURN TO DEFAULT
    //
    // FIX: previousEntryTime is now also cleared here so that
    // the gap between the last item of one batch and the first
    // item of the next batch is NOT measured as an intra-batch
    // gap. Without this, a pause between batches would produce
    // a tiny phantom entryGap on the first IR1 of the new
    // batch, triggering a spurious FF slowdown.
    //
    // Fires only after IR2 confirms the belt is empty.
    // ========================================================
    if (materialCount == 0) {
      targetPWM         = DEFAULT_SPEED;
      integral          = 0;
      previousEntryTime = 0;   // FIX: prevents inter-batch gap measurement
      entryGap          = 0;
      clearAllFFEvents();
    }

    // ========================================================
    // RUN MOTOR
    // ========================================================
    motorRun(targetPWM);

    // ========================================================
    // LCD UPDATE (every 250 ms)
    // ========================================================
    if (now - lastLCDUpdate >= 250) {
      lastLCDUpdate = now;
      updateLCDLive();
    }
  }
}

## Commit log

2026-04-23 Add files via upload
    assembly file of project
2026-04-25 file moved
    [Gear frame couple.SLDPRT]
2026-04-25 FILE MANAGEMENT
    [Arduino_Uno.step.SLDPRT, Bearing Couple.SLDPRT, Conveyor frame corner male 2.SLDPRT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]
2026-04-25 folders added
    [Gear frame couple.SLDPRT]
2026-04-25 file update
    [Conveyor Frame with support connector.SLDPRT, Conveyor Frame with support connector.STL, Conveyor Frame.SLDPRT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]
